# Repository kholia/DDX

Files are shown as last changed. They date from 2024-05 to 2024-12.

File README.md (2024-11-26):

# Intro

For help, please see the [DDX manual](./Manual-for-DDX.md). To purchase an assembled and fully tested DDX-Commercial board please [reach out to us over email](mailto:dhiru.kholia@gmail.com?subject=[DDX]%20Purchasing%20DDX).

The 'Direct Digital Transceiver' (DDX) project. DDX is a radio transceiver
(rig) which is rugged, simple and reliable.

DDX-1 is a 'silent' radio which can be heard almost all over the world!

Current versions:

- DDX-Commercial-7: 5W+ digital transceiver (Commercial, Latest Upgraded Version)

- DDX-1 R1.10: 5W digital transceiver (FOSS)

For a truly portable backpack setup you can combine DDX with the [FT8
Radio](https://play.google.com/store/apps/details?id=com.bunzee.ft8radio)
Android app.

Demo Pic 0

Sample QSO (from Pune to Medellin on 10m, 15691km) on DDX-1:

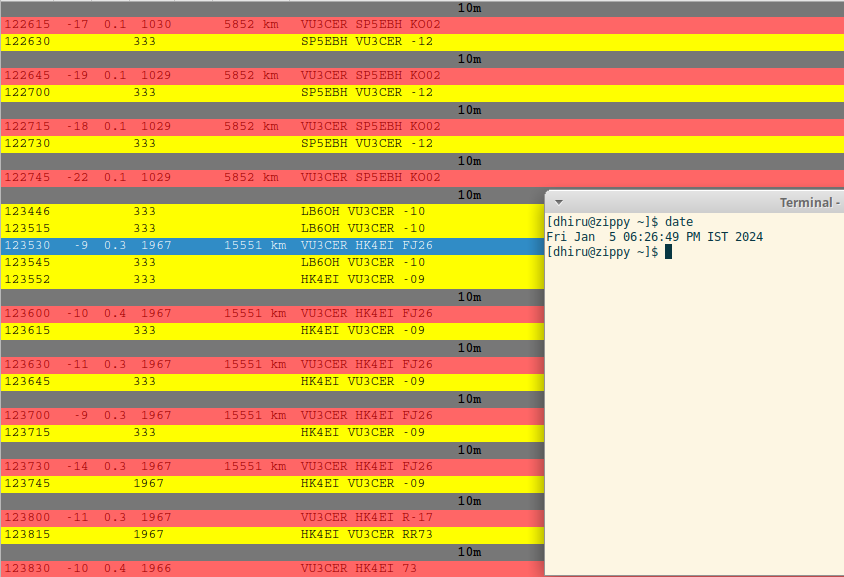
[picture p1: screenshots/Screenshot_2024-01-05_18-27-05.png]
Medellin QSO


QSO with Paraguay:

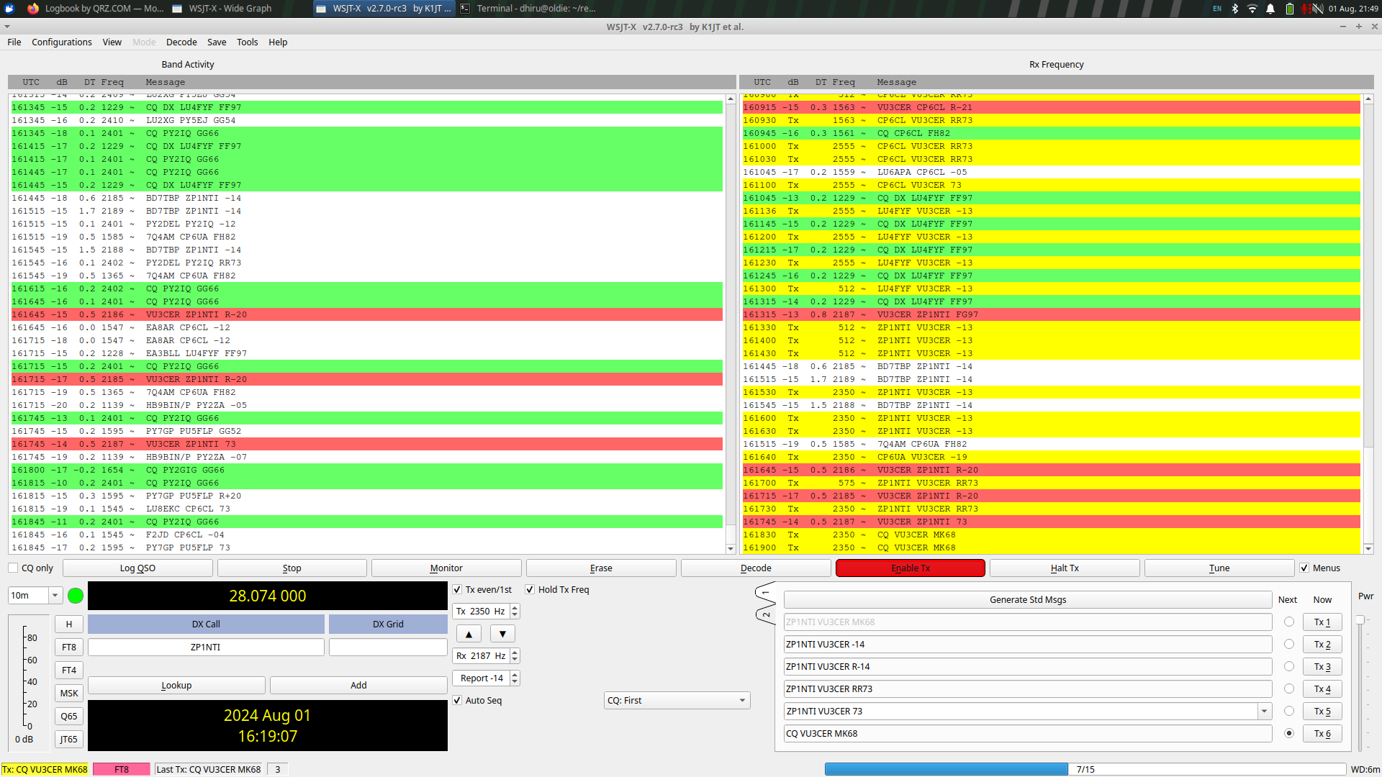
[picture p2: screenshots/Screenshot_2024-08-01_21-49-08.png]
Paraguay QSO


Who doesn't want a QSO from Medellin after binge-watching Narcos? ;)

Another sample QSO with `WW1WW` (Pune to USA):

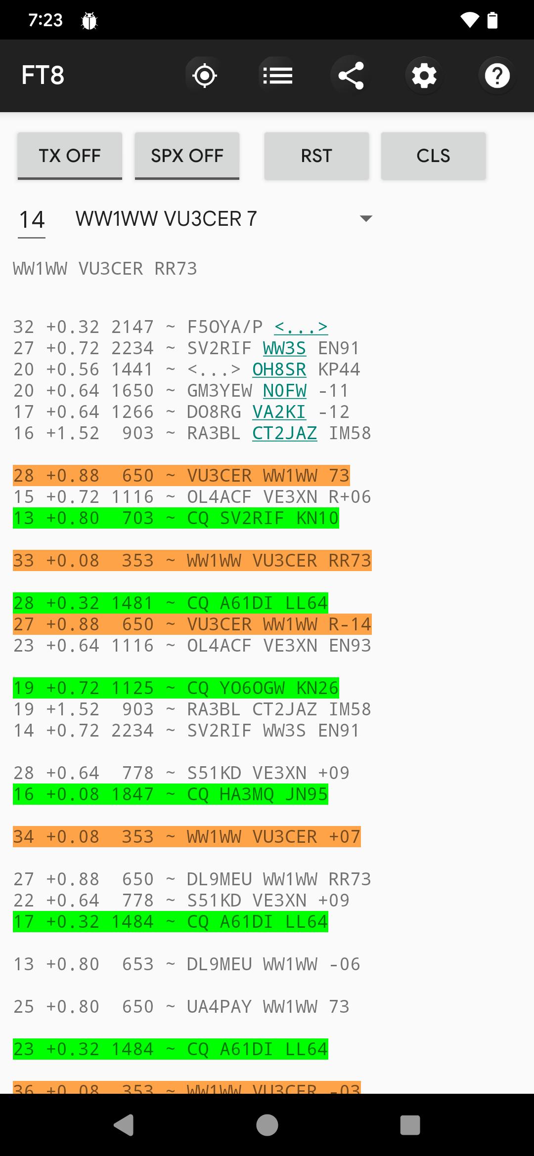
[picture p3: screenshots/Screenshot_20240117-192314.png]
USA QSO


## Render (DDX Commercial)

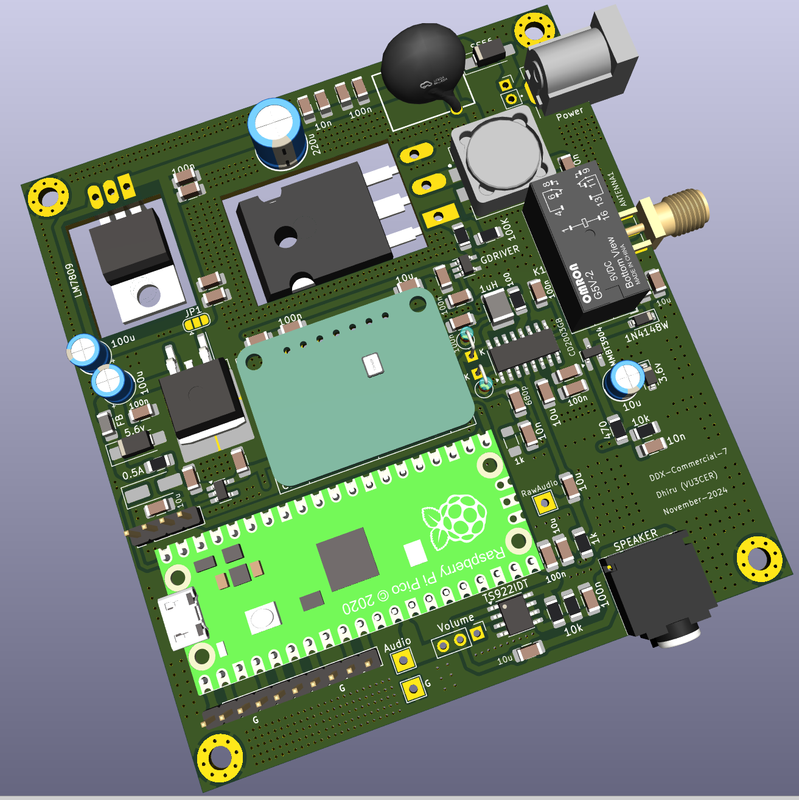
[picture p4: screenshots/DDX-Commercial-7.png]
DDX-Commercial-1


5W+ transceiver based on Pico 2 MCU platform. Beats IC-705 in terms of
efficiency and power consumption!

## Features (DDX-1)

- Single USB-C cable for handling both Audio + CAT control

- True 5W output on all HF bands. It even outputs ~1-2 W @ 50 MHz! (We now just
  need a 6m capable receiver section to build a 6m digital transceiver).

- Rock-solid PA which handles open, short, and bad SWR conditions (1:10 SWR
  tested). We knowingly stress-test it with untuned antennas and still manage
  DX (not a recommended practice for sure though).

- Rock-steady VFO which does NOT drift even under exposed conditions.  Yes - it
  receives WSPR at 28 MHz just fine.

- Reliable T/R switching based on a DPDT relay

- Switchable BPF support to get rid of BCI and other interferences (tested
  against OTH radar + 100 kW AM station in close visual proximity)

- No toroids to wind (assuming an external LPF bank is in use) ;-)

- The IRF510 final remains as cool as a cucumber (Class-D operation) - a small
  heat sink is more than enough.

- Avoids problems associated with the 'audio frequency counting' approach used
  by earlier designs. DDX-1 has a bit-perfect, deterministic TX output.

- It works beautifully with the 'FT8 Radio' app
  (https://github.com/kholia/DigitalRadioReceiverSupport/). The 'FT8 Radio' app
  handles FT8 decoding well in real time (Native MCU decoders offer significantly
  reduced performance at the moment). The app can decode 35++ stations at a time,
  and even large screens can fill up very rapidly - such is the receiver's
  performance (with a BPF)!

- DDX-1 comes with a free, open-source AGPLv3 licensed firmware.

- No calibration is (ever) required. Just pick up DDX-1 and it is ready to go
  on air.

- Low cost (cost-effective)

- Stress tested by WSJT-Z for multiple days

- DDX-1 routinely receives FT8 traffic from 80 to 100+ countries using a simple
  5m long EFHW antenna.

## RX Performance

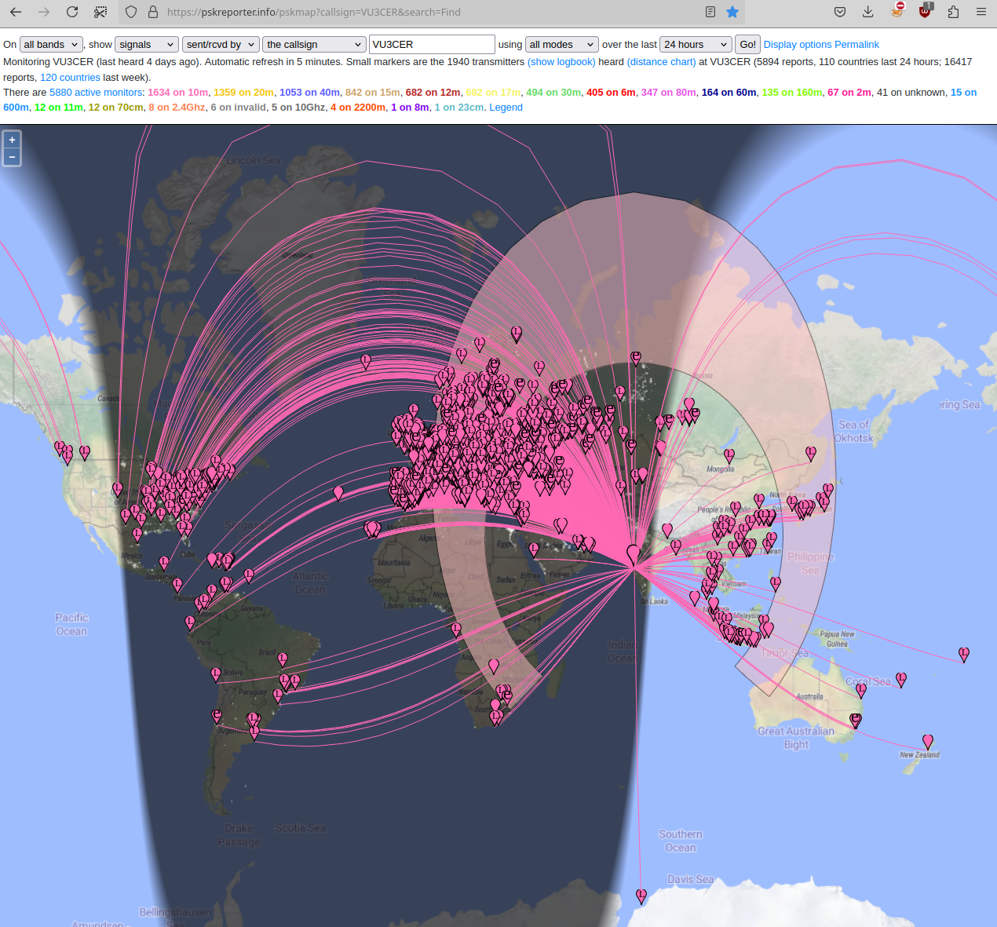
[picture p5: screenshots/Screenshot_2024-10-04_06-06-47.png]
RX Performance


Performance of CD2003-with-BPF is >= 80% of that of RSP1 SDR, at least!

I live right next to a 100 kW AM station (`Pune AIR @ 792 kHz`). Also, there is
an OTH radar nearby operating close to 28 MHz!

## TX Performance

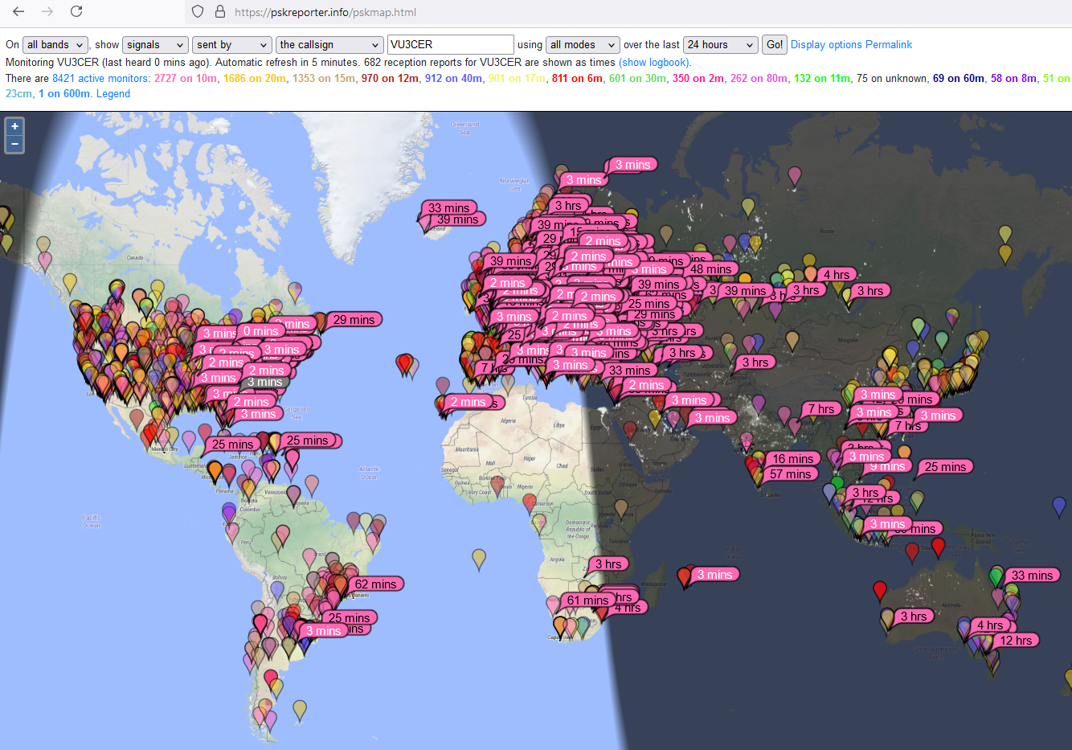
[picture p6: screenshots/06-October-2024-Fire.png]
TX Performance


## VFO stability

It receives WSPR @ 28 MHz ;)

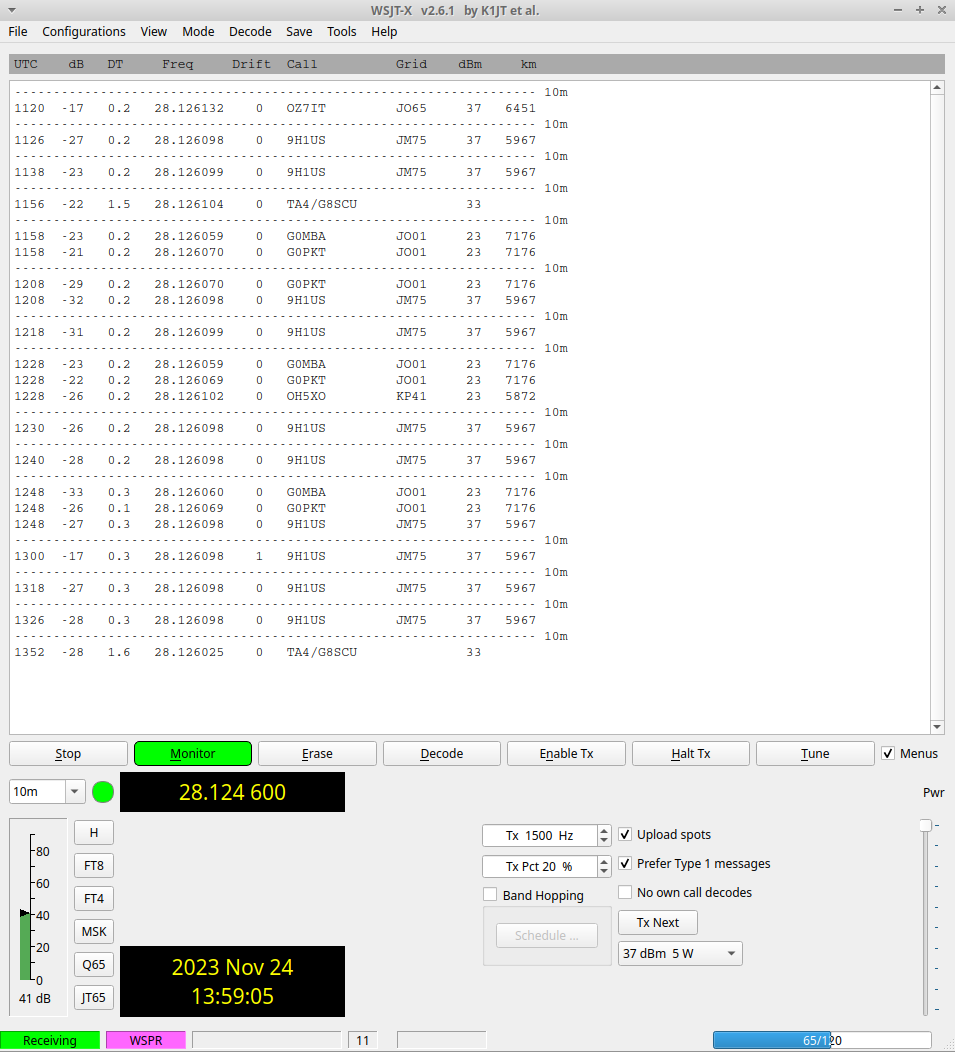
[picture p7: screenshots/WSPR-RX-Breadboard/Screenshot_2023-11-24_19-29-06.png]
Stability


## WSPR TX Performance

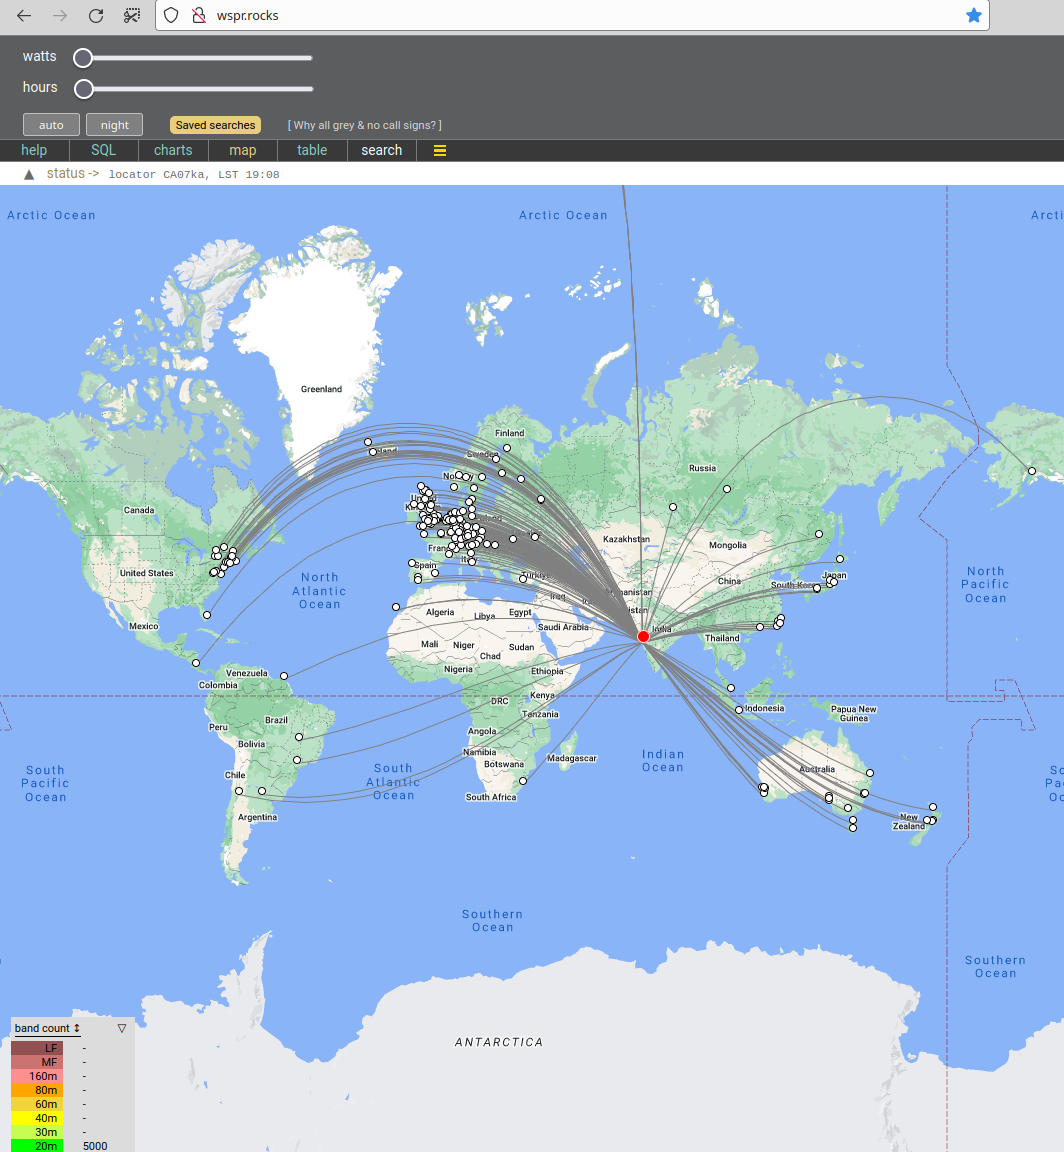
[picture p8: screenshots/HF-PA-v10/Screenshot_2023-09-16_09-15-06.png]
WSPR TX Performance


## QSOs

DDX-1 has already made hundreds of QSOs on air.

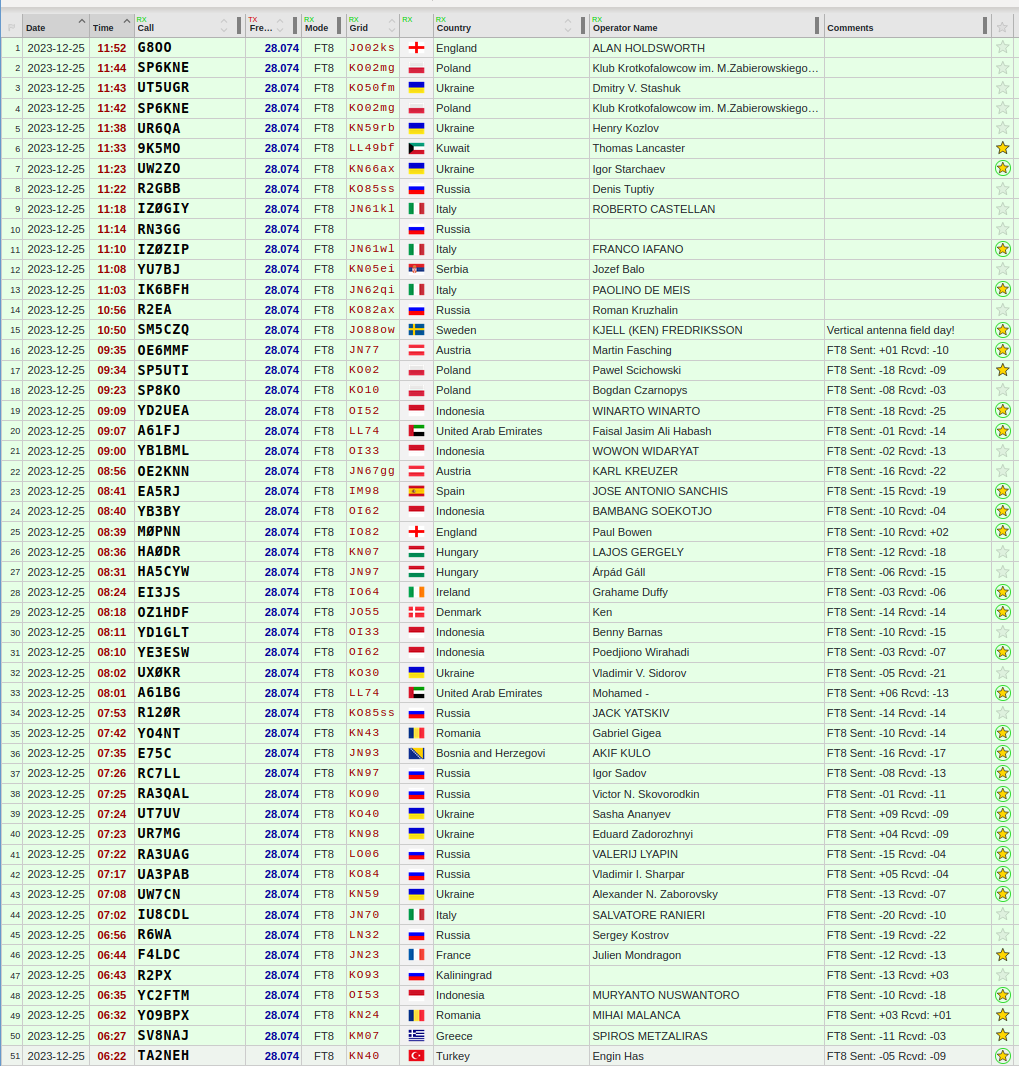
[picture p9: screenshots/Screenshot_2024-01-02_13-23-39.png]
QSOs!


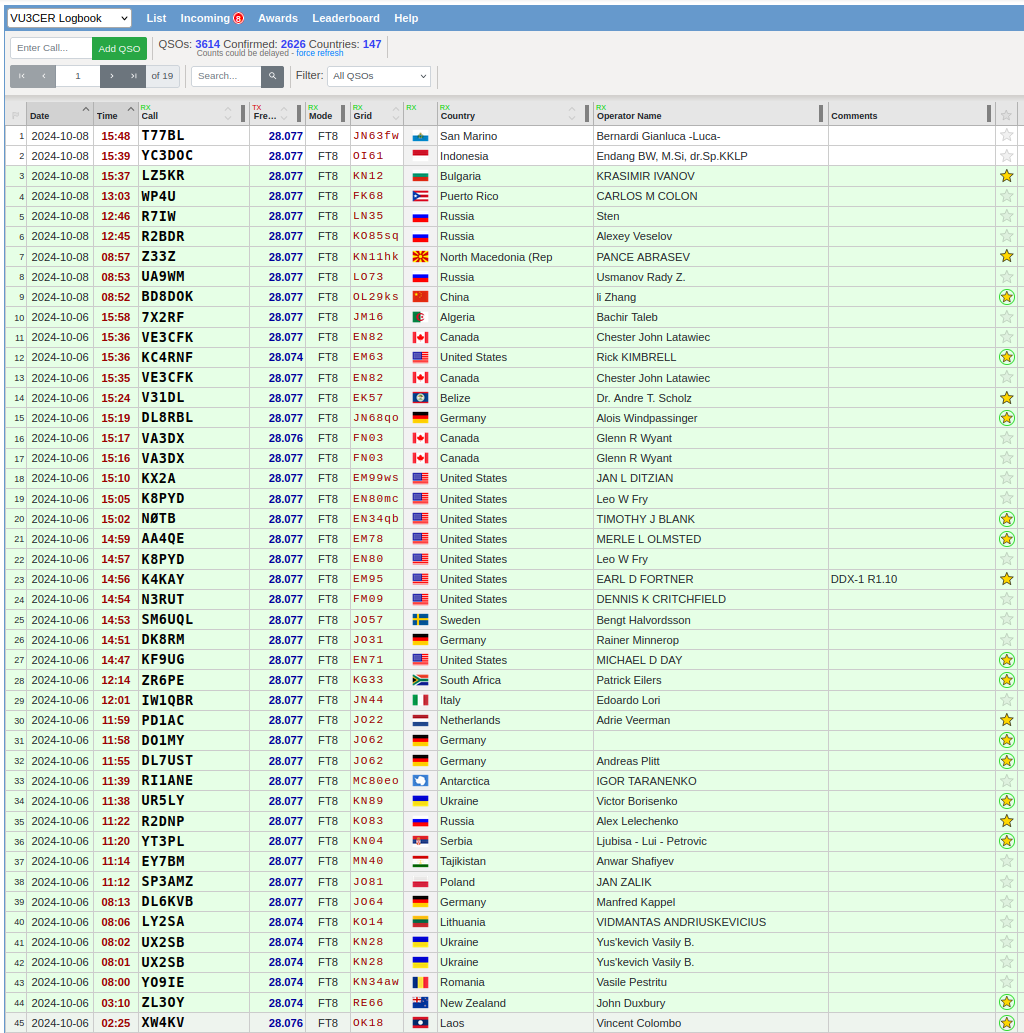
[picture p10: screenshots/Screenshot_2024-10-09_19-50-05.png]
QSOs 2!


## Power sources

DDX-1 was tested with the following power sources.

- SUGON 3005D Adjustable Digital DC Power - RECOMMENDED

- USB battery bank with PD 3.0 and >= 35W output and 15V or 20V PD decoy module
  (RECOMMENDED, safe, portable, durable)

- RUIDENG DPS5020 power supply module (@13v) powered by MEAN WELL / Mornsun SMPS

- 3S "12V" Li-ion 18650 battery pack (can be "volatile")

## Safety Tips

- Use a Common-Mode-Choke (attached between the rig, and the antenna) for
  safety against `return/back RF`.

## Resources

- https://rf-tools.com/lc-filter/

- https://github.com/WB2CBA/ADX (the design that started it all)

- http://www.learningaboutelectronics.com/Articles/Low-pass-filter-calculator.php

- https://github.com/kholia/ConsensusBasedTimeSync (receiver comes from here)

- https://github.com/kholia/Si5351-Module-Clone-TCXO/ (VFO comes from here)

- https://github.com/kholia/HF-PA-v10 (PA comes from here)

  Ruggedness philosophy: https://www.youtube.com/watch?v=4r7wHMg5Yjg

- https://www.kk5jy.net/three-wire-gp/ (recommended antenna - superb for DX)

- https://github.com/kholia/HF-Balcony-Antenna-System (another portable antenna setup)

- https://github.com/batica81/microphone-library-for-pico (Vojislav's work makes DDX-1 possible)

## Joining In

Are you interested in such projects, and spam-free technical discussions?

If yes, you might be interested in joining [the 'HAMBREWERS' Telegram group](https://t.me/+TwzGyKGe8_QI_B3y).

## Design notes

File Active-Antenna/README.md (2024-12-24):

Use KiCad 9.x to use these files.

The default layout is for `PZT2222A`.

Use `Elsie` software for opening the `.lct` files.

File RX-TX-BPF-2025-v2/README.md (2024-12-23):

Use https://tonnesoftware.com/elsie.html to open the .LCT files. The free version of Elise is sufficient.

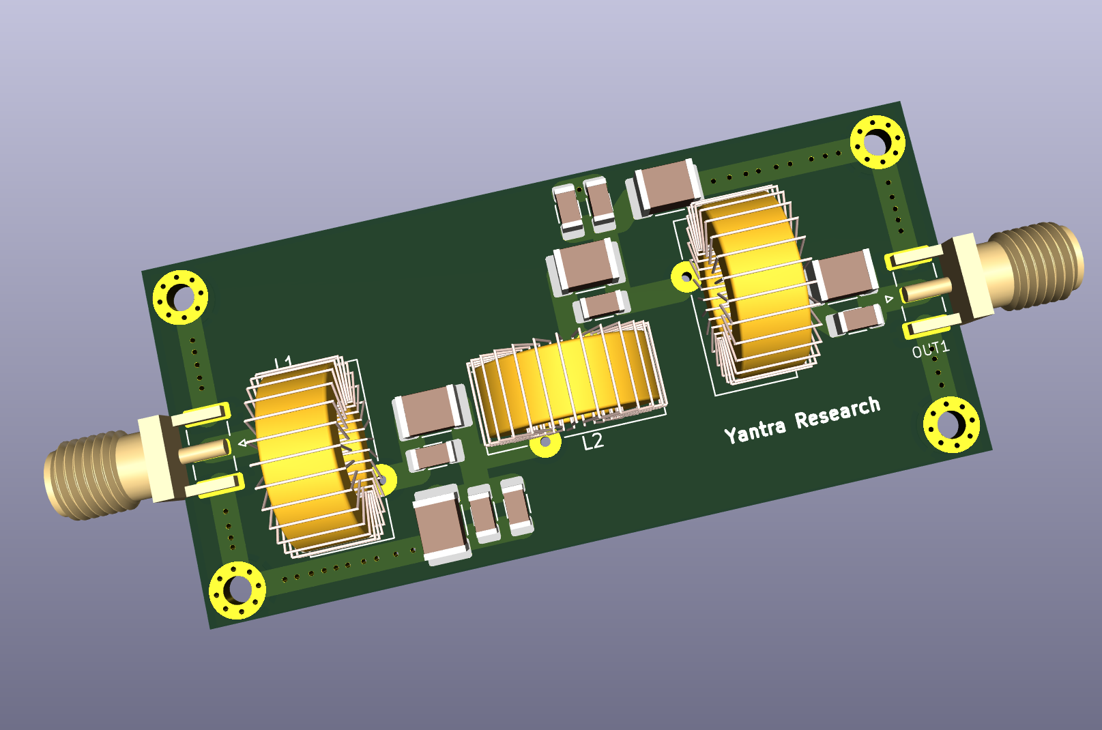
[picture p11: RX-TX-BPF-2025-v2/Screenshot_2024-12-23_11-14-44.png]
3D render


From failure to success reasons:

- Amazing guidance and confidence booster from VU2SPF at LARC 2024 conference

- Being able to measure things properly using my new DE-5000 LCR meter

- Choosing the right program (Elsie) and playing around with it

- Creating a feasible design

  Our previous design used a 27nH inductor - enough said ;)

- Seeing how inductance and capacitor values affect the response shape

- Elsie works much better (produces realistic filters) than Qucs Studio and
  https://markimicrowave.com/technical-resources/tools/lc-filter-design-tool/
  tools.

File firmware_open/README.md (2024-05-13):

Build Process:

```
$ pwd
pico-sdk

$ git checkout develop; git checkout -f
```

[Optional] Apply the following patch:

```
$ git diff
diff --git a/src/boards/include/boards/waveshare_rp2040_zero.h b/src/boards/include/boards/waveshare_rp2040_zero.h
index 281b4dc..858f930 100644
--- a/src/boards/include/boards/waveshare_rp2040_zero.h
+++ b/src/boards/include/boards/waveshare_rp2040_zero.h
@@ -16,6 +16,10 @@
 // For board detection
 #define WAVESHARE_RP2040_ZERO

+#ifndef PICO_XOSC_STARTUP_DELAY_MULTIPLIER
+#define PICO_XOSC_STARTUP_DELAY_MULTIPLIER 64
+#endif
+
 // --- UART ---
 #ifndef PICO_DEFAULT_UART
 #define PICO_DEFAULT_UART 0
```

```
export PICO_SDK_PATH=$HOME/repos/pico-sdk

export PICO_BOARD=waveshare_rp2040_zero  # note

cmake .

cmake -DCMAKE_BUILD_TYPE=Debug .  # for debugging

make -j8
```

```
$ pacmd list-sources
...
  * index: 4
	name: <alsa_input.usb-PaniRCorp_MicNode_123456-00.mono-fallback>
	driver: <module-alsa-card.c>
	flags: HARDWARE HW_MUTE_CTRL HW_VOLUME_CTRL DECIBEL_VOLUME LATENCY DYNAMIC_LATENCY
	state: RUNNING
	suspend cause: (none)
	priority: 9040
	volume: mono: 65536 / 100% / 0.00 dB
	        balance 0.00
	base volume: 64662 /  99% / -0.35 dB
	volume steps: 65537
	muted: no
	current latency: 2.54 ms
	max rewind: 0 KiB
	sample spec: s16le 1ch 16000Hz
	channel map: mono
	             Mono
	used by: 1
	linked by: 1
	configured latency: 24.99 ms; range is 0.50 .. 2000.00 ms
	card: 7 <alsa_card.usb-PaniRCorp_MicNode_123456-00>
	module: 31
	properties:
		alsa.resolution_bits = "16"
		device.api = "alsa"
		device.class = "sound"
		alsa.class = "generic"
		alsa.subclass = "generic-mix"
		alsa.name = "USB Audio"
		alsa.id = "USB Audio"
		alsa.subdevice = "0"
		alsa.subdevice_name = "subdevice #0"
		alsa.device = "0"
		alsa.card = "4"
		alsa.card_name = "MicNode"
		alsa.long_card_name = "PaniRCorp MicNode at usb-0000:04:00.4-1.3.2, full speed"
		alsa.driver_name = "snd_usb_audio"
		device.bus_path = "pci-0000:04:00.4-usb-0:1.3.2:1.0"
		sysfs.path = "/devices/pci0000:00/0000:00:08.1/0000:04:00.4/usb3/3-1/3-1.3/3-1.3.2/3-1.3.2:1.0/sound/card4"
		udev.id = "usb-PaniRCorp_MicNode_123456-00"
		device.bus = "usb"
		device.vendor.id = "cafe"
		device.vendor.name = "PaniRCorp"
		device.product.id = "4011"
		device.product.name = "MicNode"
		device.serial = "PaniRCorp_MicNode_123456"
		device.string = "hw:4"
		device.buffering.buffer_size = "64000"
		device.buffering.fragment_size = "32000"
		device.access_mode = "mmap+timer"
		device.profile.name = "mono-fallback"
		device.profile.description = "Mono"
		device.description = "MicNode Mono"
		module-udev-detect.discovered = "1"
		device.icon_name = "audio-card-usb"
	ports:
		analog-input-mic: Microphone (priority 8700, latency offset 0 usec, available: yes)
			properties:
				device.icon_name = "audio-input-microphone"
	active port: <analog-input-mic>
```

The latency and peformance of the emulated microphone is fine. Check by
recording from this device using Audacity.

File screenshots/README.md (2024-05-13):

DDX-1 prototype is hearing https://www.qrz.com/db/4W8X via the Pico's UAC2 soundcard!

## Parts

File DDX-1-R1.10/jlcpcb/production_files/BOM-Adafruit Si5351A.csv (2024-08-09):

Comment | Designator | Footprint | LCSC
SI5351A | U1 | MSOP-10_3x3mm_P0.5mm | C1509083
1k | R3,R4 | R_0805_2012Metric_Pad1.20x1.40mm_HandSolder | C17513
OSCILLATOR | Y1 | OSC-SMD_4P-L3.2-W2.5-BL_1XTV | C213404
100nF | C1,C2 | C_0805_2012Metric_Pad1.18x1.45mm_HandSolder | C49678

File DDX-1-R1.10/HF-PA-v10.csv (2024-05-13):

Reference | Value | Footprint | Datasheet | Source | Voltage | Qty
BPF1 | Pluggable BPF | footprints:Pluggable-BPF |  | JLCPCB(A) |  | 1
C1, C6, C7, C9, C14, C18, C25-C30, C32, C37, C39, C41 | 100n | Capacitor_SMD:C_1206_3216Metric_Pad1.33x1.80mm_HandSolder | ~ | LCSC | -- mixed values -- | 16
C2, C8, C13, C24, C38, C42, C43, C45, C46 | 10u | Capacitor_SMD:C_1206_3216Metric_Pad1.33x1.80mm_HandSolder | ~ | LCSC |  | 9
C3 | 100p | Capacitor_SMD:C_1206_3216Metric_Pad1.33x1.80mm_HandSolder | ~ | LCSC |  | 1
C4, C19, C35 | 10n | Capacitor_SMD:C_1206_3216Metric_Pad1.33x1.80mm_HandSolder | ~ | LCSC |  | 3
C5, C15, C44 | 100u | Capacitor_THT:CP_Radial_D5.0mm_P2.50mm | ~ | LCSC |  | 3
C10, C12 | 120p | Capacitor_SMD:C_1206_3216Metric_Pad1.33x1.80mm_HandSolder | ~ | LCSC |  | 2
C11 | 200p | Capacitor_SMD:C_1206_3216Metric_Pad1.33x1.80mm_HandSolder | ~ | LCSC |  | 1
C16 | 10u | Capacitor_SMD:C_0805_2012Metric_Pad1.18x1.45mm_HandSolder | ~ | LCSC |  | 1
C17, C20 | 1n | Capacitor_SMD:C_1206_3216Metric_Pad1.33x1.80mm_HandSolder | ~ | LCSC |  | 2
C21, C23, C47 | 100n | Capacitor_SMD:C_0805_2012Metric_Pad1.18x1.45mm_HandSolder | ~ | LCSC |  | 3
C31 | 680p | Capacitor_SMD:C_1206_3216Metric_Pad1.33x1.80mm_HandSolder | ~ | LCSC |  | 1
C36 | 10u | Capacitor_SMD:C_1206_3216Metric_Pad1.33x1.80mm_HandSolder | ~ | LCSC |  | 1
C40 | ~1n | Capacitor_SMD:C_1206_3216Metric_Pad1.33x1.80mm_HandSolder | ~ | LCSC |  | 1
CW_KEY1 | Conn_01x02 | Connector_PinHeader_2.54mm:PinHeader_1x02_P2.54mm_Vertical | ~ | NA |  | 1
D1, D2 | SS34 | Diode_SMD:D_SMA_Handsoldering | https://www.tme.eu/Document/4534c3d1273464918563ce78bdeb2ece/SS34-E3-57T.pdf | LCSC |  | 2
D3, D8, D9 | 1N4148 | Diode_THT:D_DO-35_SOD27_P2.54mm_Vertical_KathodeUp | https://www.vishay.com/docs/81857/1n4148.pdf | LCSC |  | 3
D4 | 5.1V | Diode_SMD:D_MiniMELF | ~ | LCSC |  | 1
D5 | 5.6v 5W | Diode_THT:D_DO-15_P3.81mm_Vertical_KathodeUp | ~ | LCSC |  | 1
EXT_ATU1 | EXT_ATU | footprints:PJ-307_Modded | https://cdn.hackaday.io/files/1813827760247488/JW-PJ-307-5_35mm-stereo-pcb-socket.pdf |  |  | 1
F1 | 2A | Fuse:Fuse_1812_4532Metric_Pad1.30x3.40mm_HandSolder | ~ | LCSC |  | 1
H1-H4 | MountingHole_Pad | MountingHole:MountingHole_3.2mm_M3_Pad_Via | ~ | NA |  | 4
J1 | Conn_01x06 | Connector_PinHeader_2.54mm:PinHeader_1x10_P2.54mm_Vertical | ~ | NA |  | 1
JP1, JP4 | Jumper_2_Open | Jumper:SolderJumper-2_P1.3mm_Open_TrianglePad1.0x1.5mm | ~ | NA |  | 2
JP2 | Power_Switch | Jumper:SolderJumper-3_P1.3mm_Open_RoundedPad1.0x1.5mm_NumberLabels | ~ | NA |  | 1
JP3 | Jumper_2_Open | Connector_PinHeader_2.54mm:PinHeader_1x02_P2.54mm_Vertical | ~ | NA |  | 1
K1 | Omron G5V-2 / OEN 46-05-2C | Relay_THT:Relay_DPDT_Omron_G5V-2 | http://omronfs.omron.com/en_US/ecb/products/pdf/en-g5v_2.pdf | LCSC |  | 1
L1, L2 | 360n | Inductor_THT:L_Toroid_Vertical_L10.0mm_W5.0mm_P5.08mm | ~ | DIY on Toroid |  | 2
L4 | Ferrite Bead (2A) | Inductor_SMD:L_0805_2012Metric_Pad1.05x1.20mm_HandSolder | 330Ohm 2.5A 25% 0805 Multilayer Chip Ferrite Bead - UPZ2012E331-2R5TF - Shenzhen Sunlord - LCSC | LCSC |  | 1
L5 | 1uH | Inductor_SMD:L_1206_3216Metric_Pad1.22x1.90mm_HandSolder | ~ | LCSC |  | 1
Power1 | DC-005 (Barrel Jack) | footprints:XKB_DC-005-5A-2.0_Modded | https://www.lcsc.com/product-detail/Power-Connectors_XKB-Enterprise-DC-005-5A-2-0_C381116.html | LCSC |  | 1
Q1, Q4, Q5 | 2N3904 | Package_TO_SOT_THT:TO-92_HandSolder | https://www.onsemi.com/pdf/datasheet/2n3903-d.pdf | LCSC |  | 3
Q2 | IRF510 | Package_TO_SOT_THT:TO-220-3_Horizontal_TabDown | https://www.lcsc.com/product-detail/MOSFETs_Vishay-Intertech-IRFI510GPBF_C506484.html | Mouser / LCSC (IRFI510G) |  | 1
Q3 | AOD407 | Package_TO_SOT_SMD:TO-252-2 | http://aosmd.com/pdfs/datasheet/AOD407.pdf | LCSC |  | 1
R1 | 100K | Resistor_SMD:R_1206_3216Metric_Pad1.30x1.75mm_HandSolder | ~ | LCSC |  | 1
R2, R10, R11 | 10k | Resistor_SMD:R_1206_3216Metric_Pad1.30x1.75mm_HandSolder | ~ | LCSC |  | 3
R4 | 470 | Resistor_SMD:R_1206_3216Metric_Pad1.30x1.75mm_HandSolder | ~ | LCSC |  | 1
R6 | 100 | Resistor_SMD:R_1206_3216Metric_Pad1.30x1.75mm_HandSolder | ~ | LCSC |  | 1
R7 | 1k | Resistor_SMD:R_1206_3216Metric_Pad1.30x1.75mm_HandSolder | ~ | LCSC |  | 1
R8, R9 | 4.7k | Resistor_SMD:R_1206_3216Metric_Pad1.30x1.75mm_HandSolder | ~ | LCSC |  | 2
R12 | 3.3R | Resistor_SMD:R_0805_2012Metric_Pad1.20x1.40mm_HandSolder | ~ | LCSC or short (preferred)! |  | 1
Rb1 | 1k | Resistor_SMD:R_1206_3216Metric_Pad1.30x1.75mm_HandSolder | ~ | LCSC |  | 1
Rf1 | 4.7k | Resistor_SMD:R_1206_3216Metric_Pad1.30x1.75mm_HandSolder | ~ | LCSC |  | 1
RF_OUT1 | SMA | Connector_Coaxial:SMA_Samtec_SMA-J-P-X-ST-EM1_EdgeMount | ~ | LCSC / https://www.ktron.in/ |  | 1
Rin1 | 1k | Resistor_SMD:R_1206_3216Metric_Pad1.30x1.75mm_HandSolder | ~ | LCSC |  | 1
Rl1 | 470 | Resistor_SMD:R_1206_3216Metric_Pad1.30x1.75mm_HandSolder | ~ | LCSC |  | 1
RV1 | 10k | Connector_PinHeader_2.54mm:PinHeader_1x03_P2.54mm_Vertical | ~ | NA |  | 1
RV2 | 20k | Connector_PinHeader_2.54mm:PinHeader_1x03_P2.54mm_Vertical | ~ | NA |  | 1
RZ1 | RP2040-Zero | footprints:RP2040-Zero | https://www.waveshare.com/wiki/RP2040-Zero |  |  | 1
SPK1 | SPEAKER | footprints:PJ-307_Modded | https://cdn.hackaday.io/files/1813827760247488/JW-PJ-307-5_35mm-stereo-pcb-socket.pdf |  |  | 1
T1 | Bifilar XFMR | footprints:IND_SRF1260A-4R7Y-Longer-Pads | https://www.digikey.com/en/products/detail/bourns-inc/SRF1260A-4R7Y/4340156 | Mouser / DigiKey / Farnell |  | 1
U1 | L7805 (D2PAK) | Package_TO_SOT_SMD:TO-263-2 | https://www.st.com/resource/en/datasheet/l78.pdf | LCSC |  | 1
U2 | UCC27517ADBVR | Package_TO_SOT_SMD:SOT-23-5_HandSoldering | https://www.lcsc.com/product-detail/Gate-Drive-ICs_Texas-Instruments-UCC27517ADBVR_C2653784.html | LCSC |  | 1
U3 | L7812 | Package_TO_SOT_SMD:TO-252-2 | https://www.st.com/resource/en/datasheet/l78.pdf | LCSC |  | 1
U4 | AMS1117-3.3 | Package_TO_SOT_SMD:SOT-223-3_TabPin2 | http://www.advanced-monolithic.com/pdf/ds1117.pdf | LCSC (Hottech make is fine!) |  | 1
U5 | SI5351_Module | footprints:SI5351 Module | https://github.com/kholia/Si5351-Module-Clone-TCXO/ (MUST!) | TCXO is a must! |  | 1
U7 | CD2003GB_GP | Package_DIP:DIP-16_W7.62mm | https://www.ak-modul-bus.de/cat/documentation/CD2003.pdf | eBay / https://inkocean.in/ |  | 1
U8 | MCP6002 | Package_DIP:DIP-8_W7.62mm | https://www.microchip.com/en-us/product/mcp6002 | Mouser / DigiKey / Semikart |  | 1

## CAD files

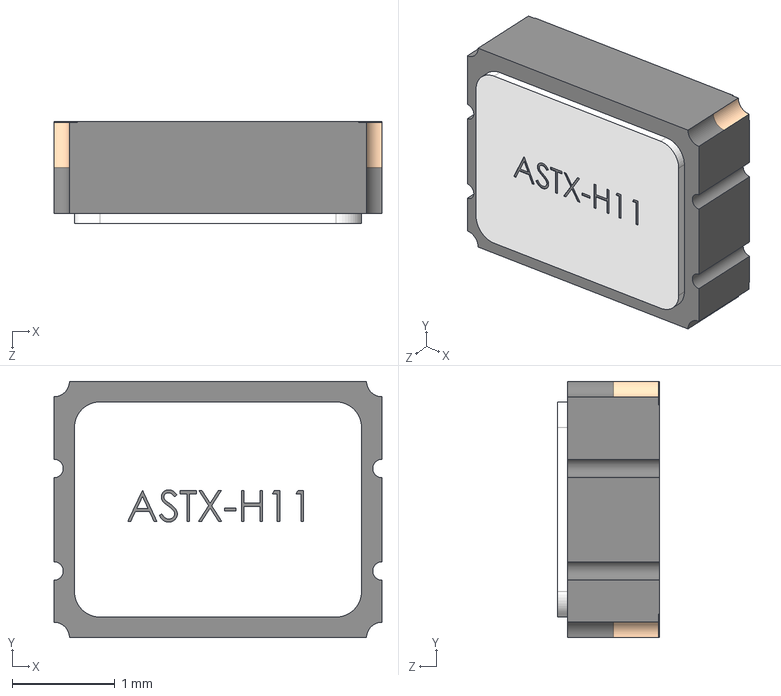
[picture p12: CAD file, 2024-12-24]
Active-Antenna/models/ASTX-H11-25.000MHZ-T.step
3.20 x 2.50 x 1.00 mm

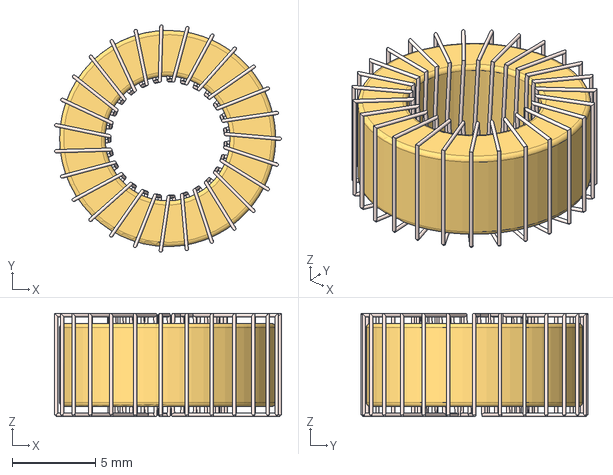
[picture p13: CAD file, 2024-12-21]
RX-TX-BPF-2025-v2/models/T50-6.step
13.7 x 13.7 x 6.20 mm

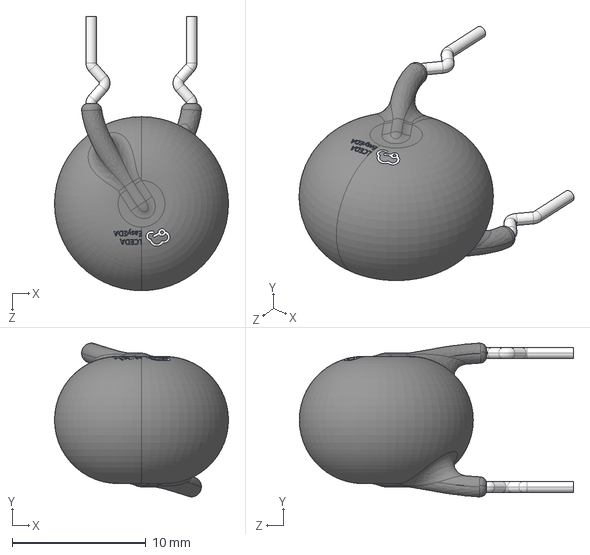
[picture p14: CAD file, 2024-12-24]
Active-Antenna/models/RES-TH_L13.0-W10.0-H21.0-P7.50-D0.8-S10.00.step
13.0 x 11.5 x 20.5 mm

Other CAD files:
experiments/DDX-EVO-3/models/TO220andHeatsinkAssy.STEP
experiments/DDX-EVO-2/models/TO220andHeatsinkAssy.STEP
DDX-1/models/5019.STEP
DDX-Commercial-1/DDX-QSD-1/models/CUI_DEVICES_SJ1-3523N.step
DDX-Commercial-1/DDX-QSD-2/models/SO-8_S_LIT.step
DDX-Commercial-1/Dongle/models/XIAO RP2350_.step
DDX-Commercial-1/Pico-WSPR-TX-250mW-board/models/SMD_4P-L6.0-W6.0-H5.0-LS10.0-P4.5.step
DDX-EVO-3/models/TO-220-3 Bend Mirror.stp
experiments/Digital-PA-Push-Pull-Final-v2/models/SMA-angled.STEP
experiments/Digital-PA-Push-Pull-Final-v3-Simple/models/SMA-angled.STEP
experiments/MiniSWR-Interface/models/CON-SMA-EDGE-S--3DModel-STEP-56544.STEP
experiments/Pluggable-BPF-Design/BPF-1.step
experiments/RX-TX-BPF-2025/RX-TX-BPF/models/T50-6.step
DDX-Commercial-1/DDX-QSD-1/models/SO-8_S_LIT.step
DDX-Commercial-1/DDX-QSD-2/models/CUI_DEVICES_SJ1-3523N.step
Active-Antenna/models/1564889-62.stp
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

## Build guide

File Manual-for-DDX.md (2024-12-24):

# Overview

DDX is a rugged 5W+ digital transceiver featuring manual band switching and
flexible power capabilities. Designed for reliability and ease of use, it's
perfect for digital modes like FT8.

DDX is brought to you by `Yantra Research`!

# Supported Modes

- FT8

# Other Modes

- WSPR (a dedicated firmware is in the works)

- FT4 (support can be added as per demand)

# Power Specifications

- ~5W output @ 15v on 28 MHz (after strong BPF)

- ~7W output @ 20v on 28 MHz (after strong BPF)

# Requirements

The following items are required for operating DDX:

- Power Source (Choose one)

  - USB PD 3.0 battery bank (portable and flight-safe option) - RECOMMENDED!

  - Traditional "12V" battery (4S LFP or 3S Li-ion or lead-acid)

  20v input (typically via PD 3.0) is RECOMMENDED!

- An antenna

  For field operations, we recommend getting / building an EFHW antenna.

  See https://github.com/kholia/HF-Balcony-Antenna-System for an example.

  https://www.kk5jy.net/three-wire-gp/ is a solid choice as well.

  The `Banggood` store also sells an EFHW 49:1 transformer for a reasonable
  price.

- Laptop / PC / Android phone

  The laptop can run the standard WSJT-X software.

  On Android, use our `FT8 Radio` app from Google Play Store.

- TX-BPF (*HIGHLY RECOMMENDED* for good performance and compliance, *REQUIRED* if you have radio interference problems)

  Update (December-2024): [We have open-sourced our TX-BPF designs here](https://github.com/kholia/DDX/tree/master/RX-TX-BPF-2025-v2).

  Tip: Buy one filter for your favorite band and then keep adding more later on

  Sources: eBay / AliExpress

  Cost: ~45 USD

  This TX-BPF helps your other radios as well and is a one-time investment.

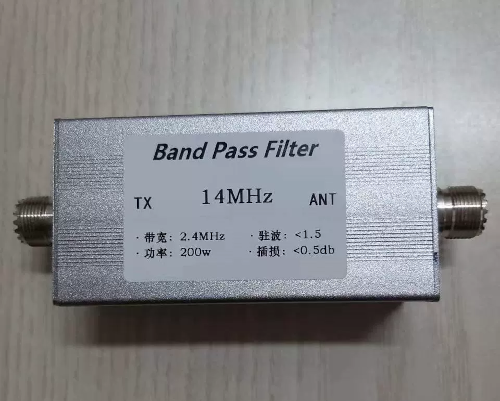
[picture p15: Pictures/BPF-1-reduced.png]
TX-BPF 1
  

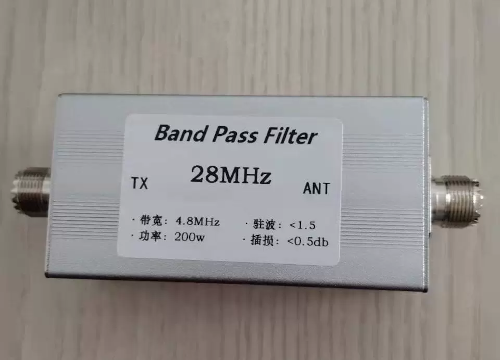
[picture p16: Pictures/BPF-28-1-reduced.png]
TX-BPF 2
  

  While many amateur radio operators focus *solely* on antenna optimization,
  the significant benefits of TX-BPF filters are often overlooked or
  under-discussed in the hobby!

  Even with HOA antenna restrictions, you can still optimize your station's
  performance through proper TX-BPF filtering.

- [Optional] Common-mode choke (CMC)

  Can be useful depending on your operating conditions.

- [Optional] PD Trigger Module

  Something like [this module](https://punoscho.in/product/usb-qc-pd-afc-trigger-decoy-board-module-15v/).

- [Optional] 10 meters plus of coax cable if operating an EFHW antenna.

# Supplied components

- 2 x mica insulator pads (for IRF510 and 7809 regulator)

- 2 x TO-220 bushes (for IRF510 and 7809 regulator)

- 2 x steel screws + spring washers + regular washers + nuts

- 1 x 5.5x2.1mm DC power cable (male connector)

- [Optional] Small TO-220 + TO-3 heat sinks

- [Optional] M3 standoffs

# Assembly Steps

- Connect the fully assembled DDX board to a heat sink (heat sink can supplied
  as an option).

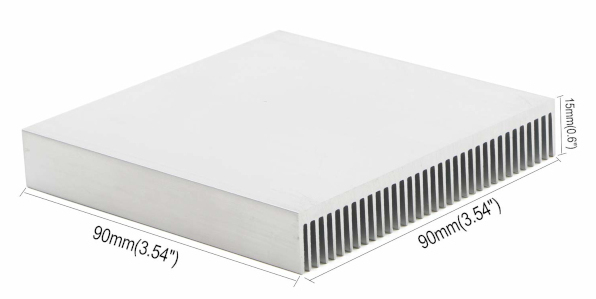
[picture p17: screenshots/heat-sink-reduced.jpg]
Heat Sink
  

  This above heat sink needs two holes to be made in it. A 3mm bit on a battery
  powered hand drill is sufficient for the job.

  [ALTERNATE HEAT SINKING OPTION]

  You can also use two smaller heat sinks like the following:

  - https://etstore.in/index.php/product/8087/ (Small TO-220 heatsink)

  - https://www.electronicscomp.com/heat-sink-to3-40mm (Yes - a TO-3 heatsink)

  The whole assembled PCB can then be raised on M3 standoffs.

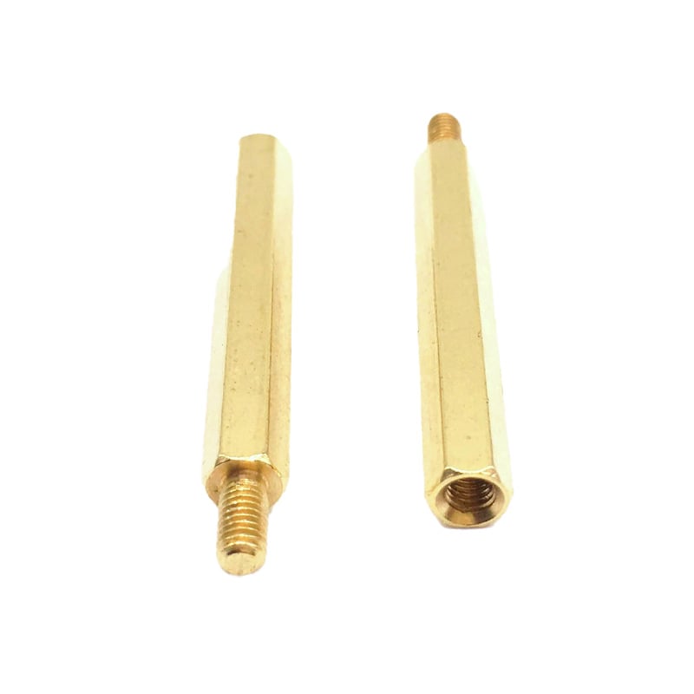
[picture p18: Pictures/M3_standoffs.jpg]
M3 standoffs
  

  https://robu.in/product/m3-x-35mm-male-to-female-brass-hex-threaded-pillar-standoff-spacer-12-pcs/

- Put the DDX board into a suitable enclosure of your choice. This is optional
  for home usage.

- Done!

# Power-on sequence

- First, connect the Micro-USB cable from DDX to the PC or phone

- Next, turn on the DC power supply (using the onboard switch)

# Usage (with WSJT-X)

* Configure WSJT-X with your callsign and grid.

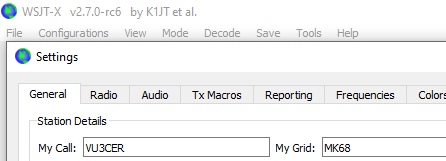
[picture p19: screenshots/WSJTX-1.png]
WSJT-X 1
  

* Select `MicNode` as the Soundcard Input.

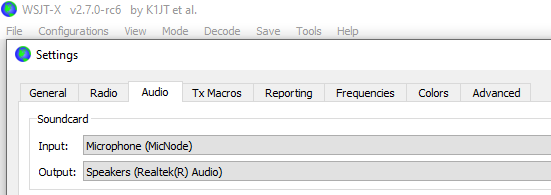
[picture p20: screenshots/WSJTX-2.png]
WSJT-X 2
  

  Tip: The `Soundcard Output` setting does NOT matter.

* Ensure the following default settings are present.

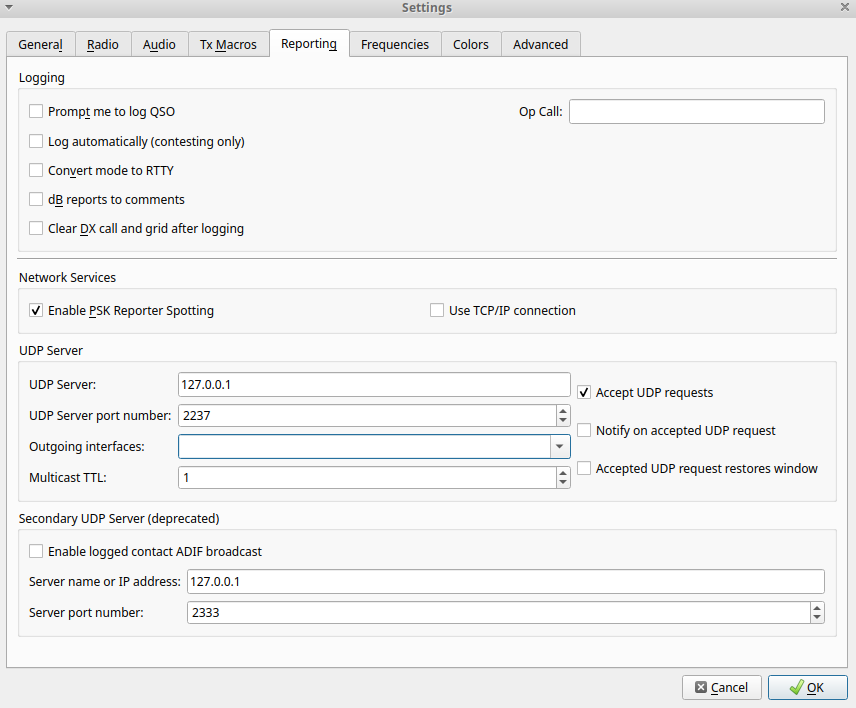
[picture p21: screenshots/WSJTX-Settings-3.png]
WSJT-X 3
  

* Launch the [wsjtx_helper/transceiver_server.exe](https://github.com/kholia/DDX/raw/refs/heads/master/wsjtx_helper/transceiver_server.exe) program.

* That's it!

# Usage (with `FT8 Radio` app on Android)

* Install `FT8 Radio` app from Google Play Store.

* Launch the app and go to settings (`gear icon`).

  Configure settings and choose `DDX` as the radio.

  NB: Restart the app forcefully.

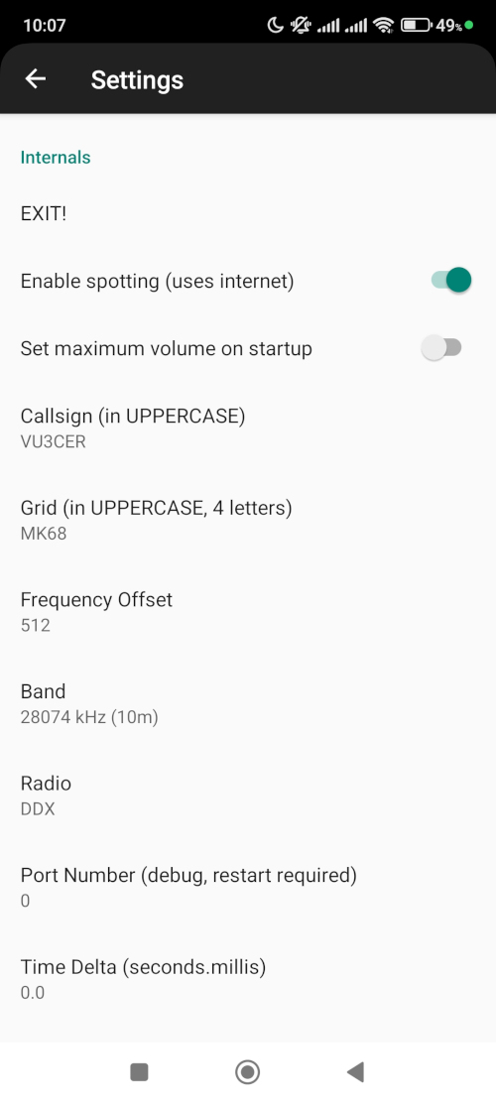
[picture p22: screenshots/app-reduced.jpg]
FT8 Radio
  

* Connect DDX to the phone using a Micro-USB cable and a reliable OTG adapter.

* Done!

PS: See https://github.com/kholia/DigitalRadioReceiverSupport/tree/master/NewApp for more help.

# Tips

For best results, we recommend syncing time on your laptop / PC using
https://www.timesynctool.com/ software.

On Android, open the https://time.is/ site to see the clock delta.

# Features

- It comes as a fully tested-on-air board with minimal assembly required.

- Single USB connection for Audio + CAT control

  DDX has a built-in 'sound card'

- Rock-solid PA which handles open, short, and bad SWR conditions (~10:1 SWR
  tested)

- Rock-steady VFO which does NOT drift even under exposed conditions. Yes - it
  receives WSPR at 28 MHz just fine.

- Reliable T/R switching based on a DPDT relay

- No toroids to wind with the external TX-BPF in use ;-)

- The final MOSFET remains as cool as a cucumber (Class-D operation)

- DDX has a bit-perfect, deterministic TX output

  We simply do NOT use the audio tones emitted by the PC (or phone).

  We implement the various FSK encoders on the MCU itself.

- It works beautifully with the 'FT8 Radio' app
  (https://github.com/kholia/DigitalRadioReceiverSupport/). The 'FT8 Radio' app
  handles FT8 decoding well in real time (Native MCU decoders offer significantly
  reduced performance at the moment). The app can decode 35++ stations at a time,
  and even large screens can fill up very rapidly - such is the receiver's
  performance (with a BPF)!

  Note: The FT8CN app is NOT supported.

- No calibration is usually required. Just pick up DDX and it is ready to go on
  air. It comes with 26 MHz 0.5ppm TCXO as a standard.

- Low cost (cost-effective)

- Stress tested by WSJT-Z and WSJT-X for multiple days

- DDX routinely receives FT8 traffic from 80 to 100+ countries using a simple
  5m long EFHW antenna with a BPF attached.

  And we use a SMPS with RuiDeng DC-DC buck module with >= 100mV ripple in our
  testing work to "stress out" the receiver.

- All this in a compact (< 100mmx100mm) size!

# Limitations

- Special / complex callsigns are NOT supported yet.

- While we have a fully-functional VFO, it is locked to certain FT8 frequencies
  for safety reasons. You can request addition of more frequencies as needed.

# Firmware Upgrade

Note: DDX comes with the firmware installed on it.

- Disconnect all power sources

- Unplug the Pico MCU board from the computer

- Keep the white button on the Pico MCU board pressed, and connect Pico to the
  computer via a USB cable

- Upload the supplied `.uf2` firmware file to the new drive that opens up on
  your computer

- Done!

# Render

DDX-Commercial-1

# Support Resources

- [The Global Communications Transceiver](https://www.youtube.com/watch?v=b82O-rVQVpk) - Video demo of older version

- [FT8 Radio App demo](https://www.youtube.com/watch?v=OX8Knu0yh6M)

- [DDX contest writeup](https://www.electronicwings.com/users/DhiruKholia/projects/4382/global-communications-transceiver)

- https://github.com/kholia/wsjtx

# Pricing

- Option 1: Kit with all components (including Pico 2 and TCXO Si5351 module) and blank PCB: 2499 INR (shipping within India included).

- Option 2: 80% assembled boards with remaining components (including Pico 2 and TCXO Si5351 module): 3999 INR (shipping within India included).

# Note

We do NOT have the resources to provide any support at the moment. We expect
our customers to be hands-on `home brewers`.

DDX is NOT (yet) targeted at `appliance operator` category of amateur radio
operators.

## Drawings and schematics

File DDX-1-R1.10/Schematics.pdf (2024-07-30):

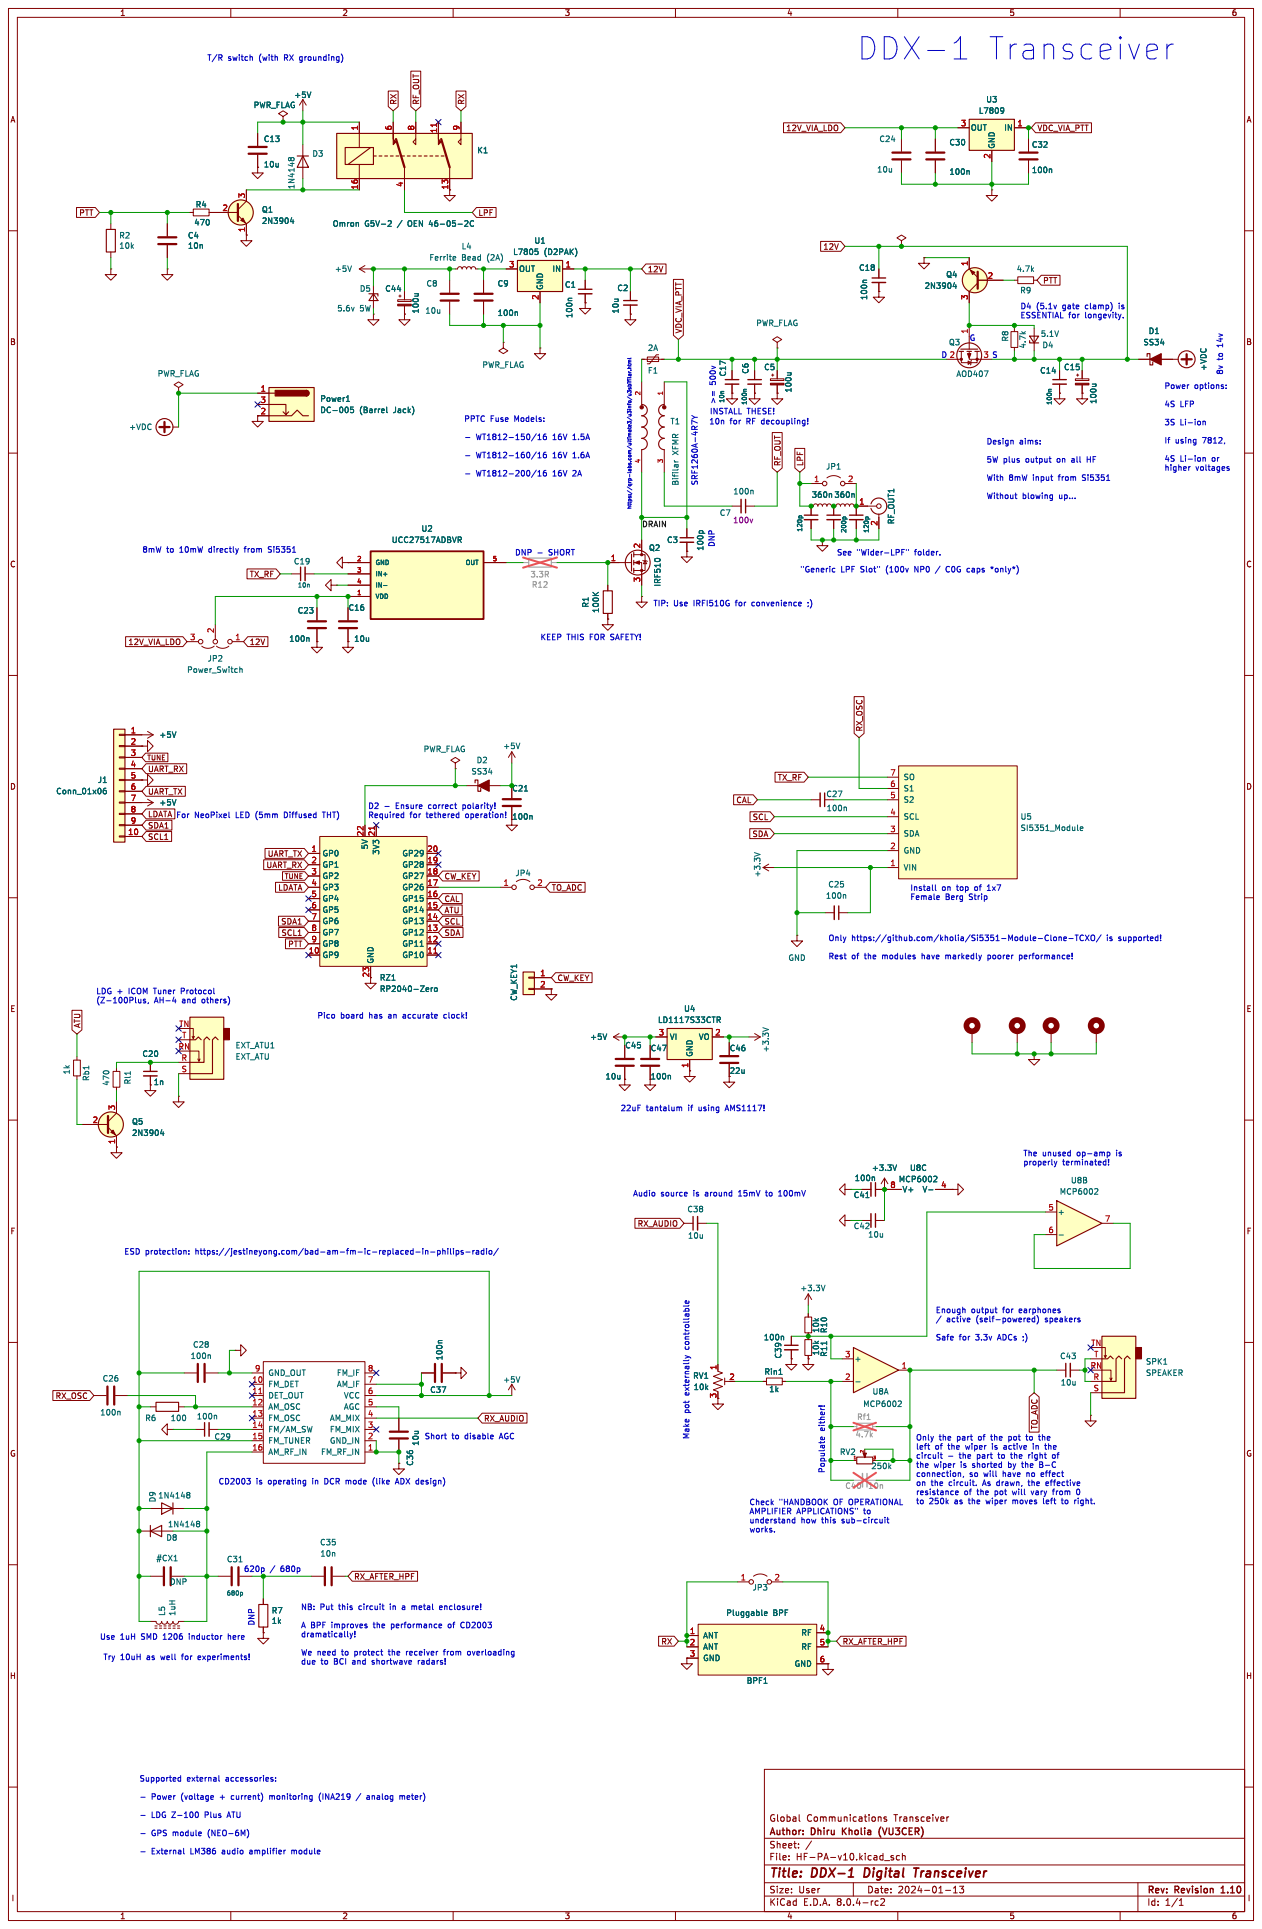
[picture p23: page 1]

T/R switch (with RX grounding)

3 +VDC
D4 (5.1v gate clamp) is ESSENTIAL for longevity. D

to 250k as the wiper moves left to right. DNP

SDesign aims: 5W plus output on all HF With 8mW input from Si5351 Without blowing up...

Enough output for earphones

left of the wiper is active in the
the wiper is shorted by the B-C

Check "HANDBOOK OF OPERATIONAL AMPLIFIER APPLICATIONS" to

dramatically! We need to protect the receiver from overloading

Try 10uH as well for experiments!

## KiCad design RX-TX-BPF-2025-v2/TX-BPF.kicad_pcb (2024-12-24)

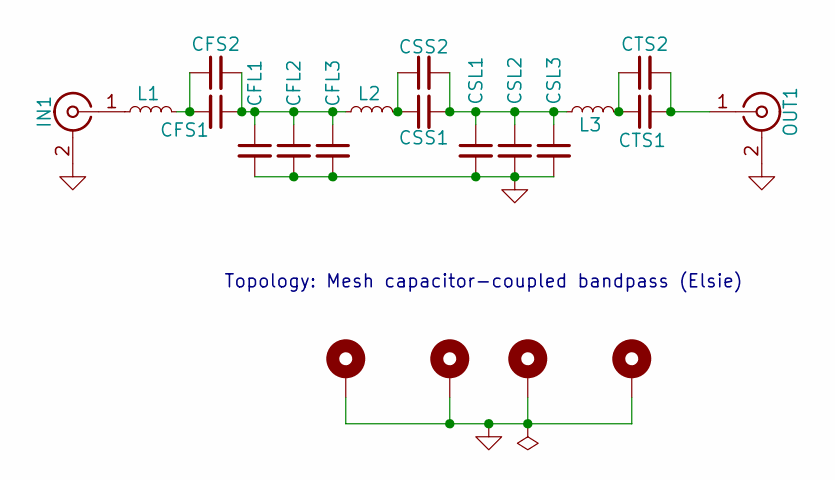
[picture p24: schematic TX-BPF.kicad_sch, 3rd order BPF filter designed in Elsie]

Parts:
CFL1, CFL2: 100n; C_1206_3216Metric_Pad1.33x1.80mm_HandSolder
CFL3: 100n; C_1812_4532Metric_Pad1.57x3.40mm_HandSolder
CFS1: 100n; C_1206_3216Metric_Pad1.33x1.80mm_HandSolder
CFS2: 100n; C_1812_4532Metric_Pad1.57x3.40mm_HandSolder
CSL1, CSL3: 100n; C_1206_3216Metric_Pad1.33x1.80mm_HandSolder
CSL2: 100n; C_1812_4532Metric_Pad1.57x3.40mm_HandSolder
CSS1: 100n; C_1812_4532Metric_Pad1.57x3.40mm_HandSolder
CSS2: 100n; C_1206_3216Metric_Pad1.33x1.80mm_HandSolder
CTS1: 100n; C_1206_3216Metric_Pad1.33x1.80mm_HandSolder
CTS2: 100n; C_1812_4532Metric_Pad1.57x3.40mm_HandSolder
H1, H2, H3, H4: MountingHole_Pad; MountingHole_2.2mm_M2_Pad_Via
IN1: SMA; SMA_Samtec_SMA-J-P-H-ST-EM1_EdgeMount
L1, L2, L3: L_Small; T50-6
OUT1: SMA; SMA_Samtec_SMA-J-P-H-ST-EM1_EdgeMount

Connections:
GND: CFL1.2, CFL2.2, CFL3.2, CSL1.2, CSL2.2, CSL3.2, H1.1, H2.1, H3.1, H4.1, IN1.2 (Ext), OUT1.2 (Ext)
unnamed: CFL1.1, CFL2.1, CFL3.1, CFS1.1, CFS2.2, L2.1
unnamed: CFS1.2, CFS2.1, L1.2
unnamed: CSL1.1, CSL2.1, CSL3.1, CSS1.2, CSS2.2, L3.1
unnamed: CSS1.1, CSS2.1, L2.2
unnamed: CTS1.1, CTS2.1, L3.2
unnamed: IN1.1 (In), L1.1
unnamed: CTS1.2, CTS2.2, OUT1.1 (In)

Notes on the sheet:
Topology: Mesh capacitor-coupled bandpass (Elsie)

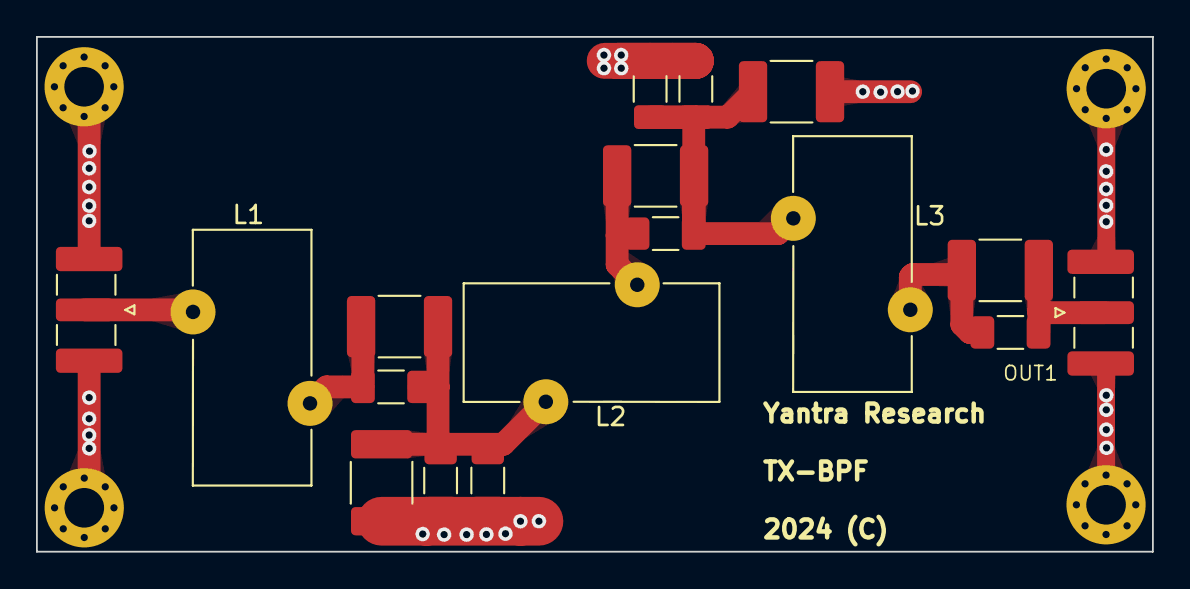
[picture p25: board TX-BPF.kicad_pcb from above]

Board: 11 copper layers, 62.0 x 28.6 mm, 21 parts (0 on the bottom side), 8 nets.

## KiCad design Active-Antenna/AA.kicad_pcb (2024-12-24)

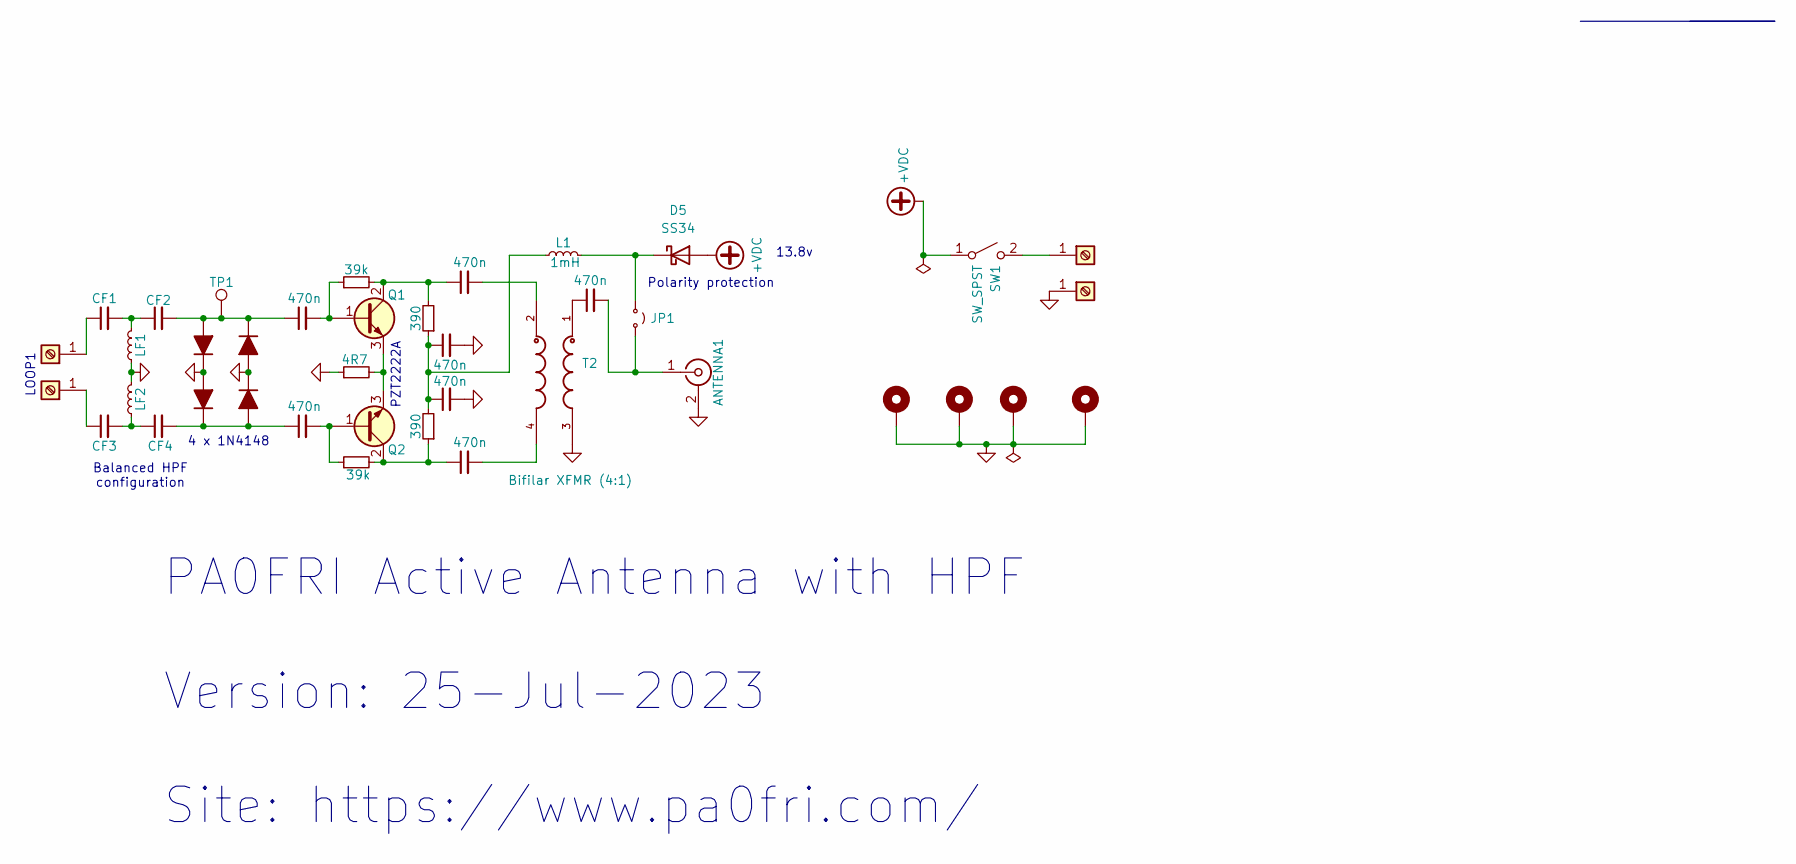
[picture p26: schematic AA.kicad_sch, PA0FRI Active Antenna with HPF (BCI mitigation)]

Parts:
ANTENNA1: SMA; SMA_Samtec_SMA-J-P-H-ST-EM1_EdgeMount
C1, C2, C3, C4, C5, C6, C7: 470n; C_1206_3216Metric_Pad1.33x1.80mm_HandSolder
CF1, CF2, CF3, CF4: 750p; C_0805_2012Metric_Pad1.18x1.45mm_HandSolder
D1, D2, D3, D4: 1N4148; D_DO-35_SOD27_P7.62mm_Horizontal
D5: SS34; D_SMA-SMB_Universal_Handsoldering
H1, H2, H3, H4: MountingHole_Pad; MountingHole_3.2mm_M3_Pad_Via
J1, J2, J3, J4: Screw_Terminal_01x01; TestPoint_THTPad_4.0x4.0mm_Drill2.0mm
JP1: Jumper_2_Small_Open; SolderJumper-2_P1.3mm_Open_RoundedPad1.0x1.5mm
L1: 1mH; L_Bourns-SRU8028_8.0x8.0mm
LF1, LF2: 1.8u; L_0805_2012Metric_Pad1.15x1.40mm_HandSolder
Q1, Q2: PZT2222A; SOT-223-3_TabPin2
R1: 4R7; R_1206_3216Metric_Pad1.30x1.75mm_HandSolder
R2, R3: 39k; R_2512_6332Metric
R4, R5: 390; R_2512_6332Metric
SW1: SW_SPST; PinSocket_1x02_P2.54mm_Vertical
T2: Bifilar XFMR (4:1); IND_SRF1260A-4R7Y-Longer-Pads
TP1: TestPoint; TestPoint_THTPad_4.0x4.0mm_Drill2.0mm

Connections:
+VDC: D5.2 (A), SW1.1 (A)
GND: ANTENNA1.2 (Ext), C3.2, C4.2, D1.1 (K), D2.2 (A), D3.1 (K), D4.2 (A), H1.1, H2.1, H3.1, H4.1, J3.1, LF1.1, LF2.2, R1.1, T2.3
unnamed: ANTENNA1.1 (In), C7.2, JP1.2 (B)
unnamed: C3.1, C4.1, L1.1, R4.1, R5.2
unnamed: C5.2, T2.2
unnamed: C6.2, T2.4
unnamed: C7.1, T2.1
unnamed: CF1.2, CF2.1, LF1.2
unnamed: CF3.2, CF4.1, LF2.1
unnamed: C1.1, CF2.2, D1.2 (A), D4.1 (K), TP1.1
unnamed: C2.1, CF4.2, D2.1 (K), D3.2 (A)
unnamed: D5.1 (K), JP1.1 (A), L1.2
unnamed: CF1.1, J1.1
unnamed: CF3.1, J2.1
unnamed: J4.1, SW1.2 (B)
unnamed: C1.2, Q1.1 (B), R2.1
unnamed: C5.1, Q1.2 (C), R2.2, R4.2
unnamed: Q1.3 (E), Q2.3 (E), R1.2
unnamed: C2.2, Q2.1 (B), R3.1
unnamed: C6.1, Q2.2 (C), R3.2, R5.1

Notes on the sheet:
PZT2222A
4 x 1N4148
Balanced HPF configuration
LOOP1
PA0FRI Active Antenna with HPF Version: 25-Jul-2023 Site: https://www.pa0fri.com/
13.8v
Polarity protection

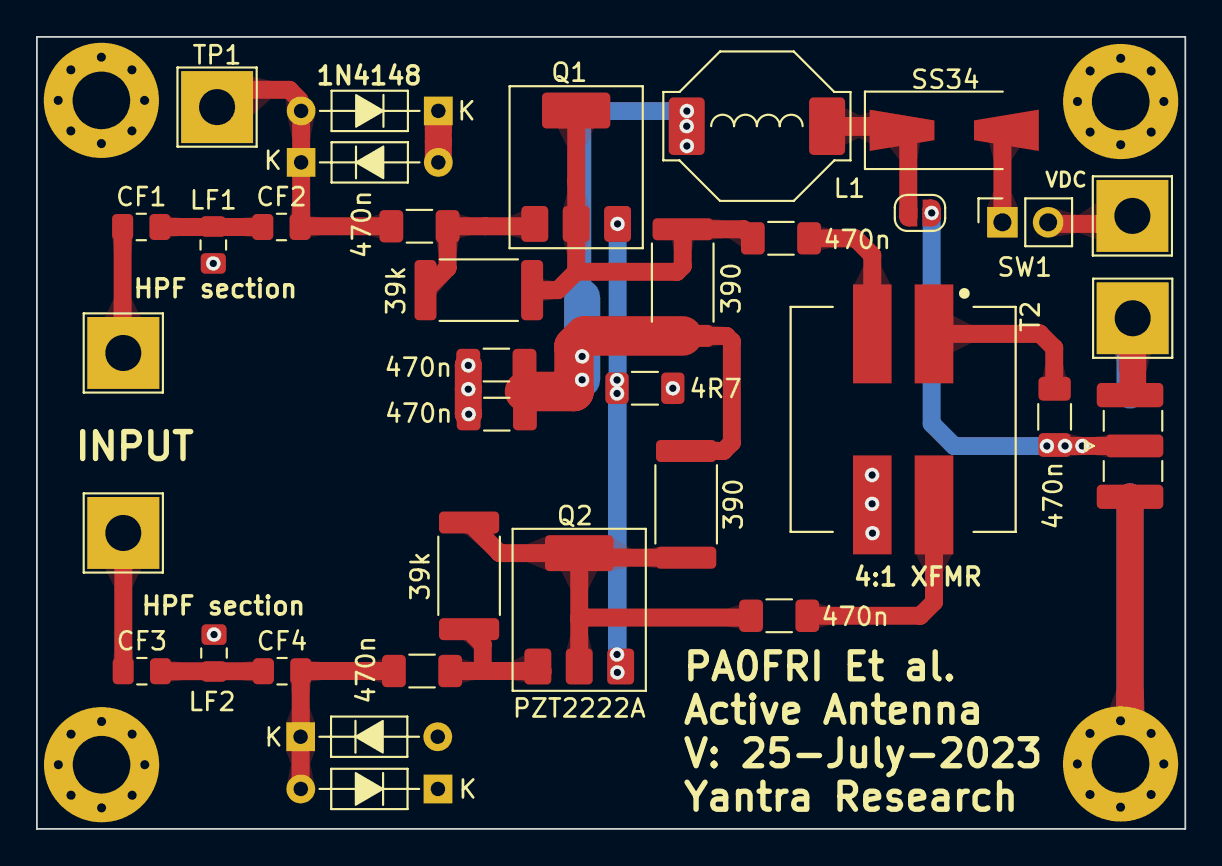
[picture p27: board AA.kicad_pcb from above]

Board: 2 copper layers, 63.8 x 44.0 mm, 39 parts (0 on the bottom side), 20 nets.

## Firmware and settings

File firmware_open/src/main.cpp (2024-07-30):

// DDX-v3 firmware

#include <string>
#include <ostream>

#include <stdio.h>
#include "pico/stdlib.h"
#include "pico/unique_id.h"
#include "analog_microphone.h"
#include "pico/multicore.h"

#include "usb_microphone.h"
#include "tusb.h"

#include "ddx_common.h"
#include "si5351.h"

#include <math.h>
#include <stdio.h>
#include <string.h>

#include "hash.h"

#include "hardware/i2c.h"
#include "hardware/timer.h"
#include "hardware/clocks.h"
#include "hardware/watchdog.h"

// ft8_lib stuff
#include "../ft8_lib/ft8/message.h"
#include "../ft8_lib/ft8/encode.h"
#include "../ft8_lib/ft8/constants.h"

#include "wspr_enc.h"

int symbolCount = 79;
int toneSpacing = 625;
#define FT8_TONE_SPACING 625  // ~6.25 Hz
#define FT8_DELAY 159  // Delay value for FT8
#define FT8_SYMBOL_COUNT 79
uint8_t tones[FT8_SYMBOL_COUNT];
int toneDelay = 159;

// #define DEBUG_ON 1

// CAT code
static uint8_t insideCat = 0;
unsigned char doingCAT = 0;
bool txCAT             = false;  // turned on if the transmitting due to a CAT command
bool message_available = false;
#define CAT_MAX 24
static char cat[CAT_MAX + 64];   // 64 avoids overflow
uint16_t offset = 1200;
static int sidx = 0;
char current_message[32];
char buffer[32];

#include "pico/stdio.h"
#include "pico/time.h"
#include "Adafruit_NeoPixel.hpp"

#define ONBOARD 16 // GP16 has 1 pixel NEOPIXEL strand connected to it

// Parameter 1 = number of pixels in strip
// Parameter 2 = Arduino pin number (most are valid)
// Parameter 3 = pixel type flags, add together as needed:
//   NEO_KHZ800  800 KHz bitstream (most NeoPixel products w/WS2812 LEDs)
//   NEO_KHZ400  400 KHz (classic 'v1' (not v2) FLORA pixels, WS2811 drivers)
//   NEO_GRB     Pixels are wired for GRB bitstream (most NeoPixel products)
//   NEO_RGB     Pixels are wired for RGB bitstream (v1 FLORA pixels, not v2)
//   NEO_RGBW    Pixels are wired for RGBW bitstream (NeoPixel RGBW products)
Adafruit_NeoPixel onboard = Adafruit_NeoPixel(1, ONBOARD, NEO_RGB + NEO_KHZ800);

// IMPORTANT: To reduce NeoPixel burnout risk, add 1000 uF capacitor across
// pixel power leads, add 300 - 500 Ohm resistor on first pixel's data input
// and minimize distance between Arduino and first pixel.  Avoid connecting
// on a live circuit...if you must, connect GND first.
// additional functions
void colorWipe(uint32_t c, uint8_t wait);

// configuration
const struct analog_microphone_config config = {
  // GPIO to use for input, must be ADC compatible (GPIO 26 - 28)
  .gpio = 26,
  // bias voltage of microphone in volts
  .bias_voltage = 1.65, // 3.3v / 2
  // sample rate in Hz
  .sample_rate = 16000,
  // number of samples to buffer
  .sample_buffer_size = SAMPLE_BUFFER_SIZE,
};

// variables
int16_t sample_buffer[SAMPLE_BUFFER_SIZE];
volatile int samples_read = 0;

void on_analog_samples_ready()
{
  samples_read = analog_microphone_read(sample_buffer, SAMPLE_BUFFER_SIZE);
}

void on_usb_microphone_tx_ready()
{
  usb_microphone_write(sample_buffer, sizeof(sample_buffer));
}

void cdc_task(void);

// Automatic calibration stuff
uint32_t f_hi_;
void pwm_int_() {
  pwm_clear_irq(7);
  f_hi_++;
}

void band_change(int idx)
{
  si5351_set_freq((freq) * 100ULL, SI5351_CLK1); // CLK1 is RX clock
}

/* Button handling code */
int btnDown(int btn) {
  if (gpio_get(btn) == 1)
    return 0;
  else
    return 1;

  return 0;
}

static void str_to_upper(char *dist, const char *str)
{
  while (*str) *dist++ = toupper(*str++);
  *dist = 0;
}

int wspr_encode(char *call, char *grid, char *dBm, uint8_t *symbols)
{
  char call_u[11], grid_u[7];

  // Call
  if ((strlen(call) < 2) || (strlen(call) > 10)) {
    printf("The length of callsign %s is invalid.\n", call);
    return -1;
  }
  str_to_upper(call_u, call);
  // for Swaziland 3DA0YZ, 3D0YZ will be used for proper decoding
  if (strncmp(call_u, "3DA0", 4) == 0) {
    size_t i;
    for (i = 3; i < strlen(call); i++) {
      call[i - 1] = call[i];
    }
    call[i - 1] = 0;
  }
  str_to_upper(call_u, call);

  // Grid
  if ((strlen(grid) != 4) && (strlen(grid) != 6)) {
    printf("The length of grid locator %s is invalid.\n", grid);
    return -1;
  }
  str_to_upper(grid_u, grid);

  printf("WSPR Message: %s %s %s\n", call, grid, dBm);

  // invoke encoder function to generate symbols
  uint8_t msgtype = wspr_enc(call, grid, dBm, symbols);

  /* printf("Channel symbols: (message type %d)", msgtype);
    int i;
    for (i = 0; i < 162; i++) {
      if (i%30 == 0) {
          printf("\n      %d", symbols[i]);
      } else {
          printf(" %d", symbols[i]);
      }
    }
    printf("\n"); */

  return 0;
}

void active_sleep_ms(unsigned int delay_by) {
  sleep_ms(delay_by);

  /* unsigned long timeStart = millis();
    while (millis() - timeStart <= delay_by) {
    // Background Work
    } */
}

int checkButton(int btn) {
  int ret = 0;

  // only if the button is pressed
  if (!btnDown(btn))
    return ret;
  active_sleep_ms(50);
  if (!btnDown(btn)) // debounce
    return ret;

  ret = 1;
  if (btn == ABORT_BTN) {
    gpio_put(PTT, 0);
    si5351_set_clock_pwr(SI5351_CLK0, 0);
    si5351_output_enable(SI5351_CLK0, 0);
  } else if (btn == TUNE_BTN) {
    gpio_put(ATU_PIN, 1);
    // Turn on the output
    gpio_put(PTT, 1);
    sleep_ms(12); // Important delay for relay switching (for OEN 46 Series)
    si5351_set_freq(((freq + offset) * 100ULL), SI5351_CLK0);
    si5351_set_clock_pwr(SI5351_CLK0, 1);
    si5351_output_enable(SI5351_CLK0, 1);
    colorWipe(onboard.Color(255, 0, 0), 0); // R
    sleep_ms(3500); // Full tune cycle (LDG Z-100 Plus Automatic Tuner)
    // Turn off the output
    si5351_set_clock_pwr(SI5351_CLK0, 0);
    si5351_output_enable(SI5351_CLK0, 0);
    gpio_put(PTT, 0);
    // colorWipe(onboard.Color(0, 255, 0), 0); // G
    colorWipe(onboard.Color(0, 0, 0), 0); // Off

    gpio_put(ATU_PIN, 0);
  }

  // wait for the button to go up again
  while (btnDown(btn))
    active_sleep_ms(10);
  active_sleep_ms(50);

  return ret;
}

bool start_tx = false;

void tx()
{
  uint8_t i;

  gpio_put(PTT, 1);
  sleep_ms(12); // Important delay for relay switching (for OEN 46 Series)
#ifndef DEBUG_ON
  si5351_set_clock_pwr(SI5351_CLK0, 1);
  si5351_output_enable(SI5351_CLK0, 1);
  si5351_drive_strength(SI5351_CLK0, SI5351_DRIVE_8MA); // Set max. power for TX (UCC driver)
  colorWipe(onboard.Color(255, 0, 0), 0); // R
#endif
  for (i = 0; i < symbolCount; i++) {
#ifndef DEBUG_ON
    si5351_set_freq(((freq + offset) * 100ULL) + (tones[i] * toneSpacing), SI5351_CLK0);
#endif
    sleep_ms(toneDelay);
  }

  // Turn off the output
#ifndef DEBUG_ON
  si5351_set_clock_pwr(SI5351_CLK0, 0);
  si5351_output_enable(SI5351_CLK0, 0);
#endif
  gpio_put(PTT, 0);
#ifndef DEBUG_ON
  si5351_set_freq((freq) * 100ULL, SI5351_CLK1); // CLK1 is RX clock, reinit rx_clock_line?
  colorWipe(onboard.Color(0, 0, 0), 0); // Off
#endif
}

void core1_entry() {
  int ret;
  while (1) {
    // checkButton(ABORT_BTN);
    // checkButton(TUNE_BTN);
    if (start_tx) {
      tx();
      start_tx = false;
    }
    sleep_ms(10);
  }
}

void colorWipe(uint32_t c, uint8_t wait) {
  for (uint16_t i = 0; i < onboard.numPixels(); i++) {
    onboard.setPixelColor(i, c);
    onboard.show();
    sleep_ms(wait);
  }
}

void crash_with_led()
{
  while (1) {
    colorWipe(onboard.Color(255, 0, 0), 100); // Red
    colorWipe(onboard.Color(0, 255, 0), 100); // Green
    colorWipe(onboard.Color(0, 0, 255), 100); // Blue
  }
}

void finite_crash_with_led()
{
  int i = 7;

  while (i >= 0) {
    colorWipe(onboard.Color(255, 0, 0), 100); // Red
    colorWipe(onboard.Color(0, 255, 0), 100); // Green
    colorWipe(onboard.Color(0, 0, 255), 100); // Blue
    i = i - 1;
  }
}

static void hash_to_string(char string[65], const uint8_t hash[32])
{
  size_t i;
  for (i = 0; i < 32; i++) {
    string += sprintf(string, "%02x", hash[i]);
  }
}

void watchdog_task();

int main(void)
{
  int ret;

  stdio_init_all();

  // Safety first
  gpio_init(PTT);
  gpio_set_dir(PTT, GPIO_OUT);
  gpio_put(PTT, 0);

  // NeoPixel stuff
  onboard.begin();
  onboard.setBrightness(25);
  onboard.show(); // Initialize all pixels to 'off'

  // sleep_ms(5000);

#ifndef DEBUG_ON
  // Initialize the Si5351 --- this will go into an infinte loop in case of problems!
  while (1) {
    ret = si5351_init(0x60, SI5351_CRYSTAL_LOAD_8PF, 26000000, 0); // I am using a 26 MHz TCXO
    if (!ret) {
      // crash_with_led(); // Dhiru's hack
      // watchdog_reboot(0, 0, 1000);
      colorWipe(onboard.Color(255, 0, 0), 100); // Red
      sleep_ms(500);
      colorWipe(onboard.Color(255, 255, 0), 100);
      sleep_ms(500);
    }
    else {
      break;
    }
  }

  colorWipe(onboard.Color(0, 0, 0), 0); // Off
  // si5351_init(0x60, SI5351_CRYSTAL_LOAD_8PF, 0, 0);
  si5351_output_enable(SI5351_CLK0, 0); // Turn of TX first - safety!
  // CLK1 is RX clock
  si5351_set_freq(freq * 100ULL, SI5351_CLK1);
  si5351_drive_strength(SI5351_CLK1, SI5351_DRIVE_4MA); // Set a bit reduced power for RX
  si5351_drive_strength(SI5351_CLK0, SI5351_DRIVE_8MA); // Set max. power for TX (UCC driver)
#endif

  // Initialize GPIOs
  gpio_init(TUNE_BTN);
  gpio_init(ABORT_BTN);
  gpio_set_dir(TUNE_BTN, GPIO_OUT);
  gpio_set_dir(ABORT_BTN, GPIO_OUT);
  gpio_pull_up(TUNE_BTN);
  gpio_pull_up(ABORT_BTN);
  gpio_set_dir(CAL, GPIO_IN);
  gpio_put(ATU_PIN, 0);

  // "Pico's" serial number
  int len = 16;
  char buff[len + 1] = "";
  pico_get_unique_board_id_string((char *)buff, len + 1);
#ifdef DEBUG_ON_VERBOSE
  printf(buff);
#endif

  uint8_t hash[32];
  char hash_string[65];
  calc_sha_256(hash, buff, len);
  hash_to_string(hash_string, hash);

  // Turn on RX
  gpio_put(PTT, 0);

  // EEPROM.get(4, cal_factor);
  // si5351_set_correction(cal_factor, SI5351_PLL_INPUT_XO);

  // Pico soundcard stuff
  if (analog_microphone_init(&config) < 0) {
    while (1) {
      tight_loop_contents();
    }
  }
  analog_microphone_set_samples_ready_handler(on_analog_samples_ready);
  if (analog_microphone_start() < 0) { // start capturing data from the analog microphone
    while (1) {
      tight_loop_contents();
    }
  }
  usb_microphone_init();
  usb_microphone_set_tx_ready_handler(on_usb_microphone_tx_ready);

  // note!
  multicore_launch_core1(core1_entry);

  while (1) {
    // run the USB microphone task continuously
    usb_microphone_task(); // calls tud_task() -> TinyUSB device task

    cdc_task(); // CAT handler -> should return fast!

    watchdog_task();
  }
  return 0;
}

// Variables
uint64_t freq = 28074000ULL; // Start on the 10m by default
uint64_t new_freq;
int32_t cal_factor = 0; // Sorted out by auto-calibration algorithm, now not required by tcxo ;)

absolute_time_t tx_timestamp;

void watchdog_task() {
  watchdog_update();

  if (start_tx == true) {
    // Another safeguard for FT8
    absolute_time_t current_timestamp = get_absolute_time();
    if (absolute_time_diff_us(tx_timestamp, current_timestamp) > 15000000ULL) {
      si5351_set_clock_pwr(SI5351_CLK0, 0);
      si5351_output_enable(SI5351_CLK0, 0);
      gpio_put(PTT, 0);
      finite_crash_with_led();
      watchdog_reboot(0, 0, 1000);
    }
  }
}

char buf[64];

extern "C" {
	void packtext77(const char* text, uint8_t* b77);
}

//--------------------------------------------------------------------+
// USB CDC
//--------------------------------------------------------------------+
// Dhiru -> Don't block in this task at all - it impacts the audio quality!
void cdc_task(void)
{
  if (tud_cdc_available())
  {
    memset(buf, 0, sizeof(buf));
    uint32_t count = tud_cdc_read(buf, sizeof(buf)); // count can be 1 here - so we have to piece 'strings' together ourselves
    // printf(count);
    // printf(sidx);

    memcpy(cat + sidx, buf, count);
    // printf(cat);
    cat[CAT_MAX - 1] = 0;
    sidx = (sidx + count) % CAT_MAX; // not perfect

    // Protocol -> a valid message starts with '*' and also ends with '*'
    char *s = strchr(cat, '*');
    char *e = strrchr(cat, '*');
    if (s != e && s != NULL && e != NULL ) { /* We may have a valid message */
      if (*(s + 1) == 'v') { // 'ready' debug
        char *response = (char *)"r";
        // Send indication for ready!
        tud_cdc_write(response, 1);
        tud_cdc_write_flush();
      } else if (*(s + 1) == 'o') {
        char *response = (char *)"o";
        offset = atoi(strtok(s + 2, "*"));
      } else if (*(s + 1) == 'm') { // message load
        char *response = (char *)"m";
        message_available = true;
        strncpy(current_message, strtok(s + 2, "*"), 32 - 1);
#ifdef DEBUG_ON_VERBOSE
        printf(current_message);
#endif
        ftx_message_t msg;
        ftx_message_rc_t rc = ftx_message_encode(&msg, NULL, current_message);
        bool is_ft4 = false;
        if (rc != FTX_MESSAGE_RC_OK) {
#ifdef DEBUG_ON_VERBOSE
          printf("Cannot parse message!\n");
          printf("RC = %d\n", (int)rc);
#endif
          // sleep_ms(1000);
          if (strlen(current_message) <= 13) {
            packtext77(current_message, (uint8_t *)&msg.payload);
            colorWipe(onboard.Color(0, 255, 255), 0); // Blue-green (cyan)
          }
	}
        int num_tones = (is_ft4) ? FT4_NN : FT8_NN;
        // Second, encode the binary message as a sequence of FSK tones
        if (is_ft4) {
          ft4_encode(msg.payload, tones);
        } else {
          ft8_encode(msg.payload, tones);
        }
      } else if (*(s + 1) == 't') { // tx on
        if (message_available) {
          char *response = (char *)"t";
          start_tx = true;
          watchdog_enable(7000, 1);
          tx_timestamp = get_absolute_time();
        }
      } else if (*(s + 1) == 'z') { // ptt off
        if (message_available) {
          char *response = (char *)"z";
#ifdef DEBUG_ON_VERBOSE
          printf("PTT OFF");
#endif
          gpio_put(PTT, 0);
        }
      } else if (*(s + 1) == 'p') { // ptt on
        if (message_available) {
          char *response = (char *)"p";
#ifdef DEBUG_ON_VERBOSE
          printf("PTT ON");
#endif
          // gpio_put(PTT, 1); // Disabled for safety
        }
      } else if (*(s + 1) == 'y') { // debug
        if (message_available) {
          char *response = (char *)"y";
        }
      } else if (*(s + 1) == 's') { // 'style' (digital mode)
        strncpy(buffer, strtok(s + 2, "*"), 32 - 1);
	puts(buffer);
      } else if (*(s + 1) == 'f') { // frequency
        char *response = (char *)"f";
        char *f = strtok(s + 2, "*");
        char *ptr;
        new_freq = strtoul(f, &ptr, 10);
        freq = new_freq;
        uint8_t band_idx;
        /* switch (new_freq) {
          case 7074000:
            band_idx = 0;
            break;
          case 14074000:
            band_idx = 1;
            break;
          case 21074000:
            band_idx = 2;
            break;
          case 28074000:
            band_idx = 3;
            break;
          } */
        // band_change(band_idx);
#ifndef DEBUG_ON
        si5351_set_freq((freq) * 100ULL, SI5351_CLK1); // CLK1 is RX clock
#endif
#ifdef DEBUG_ON_VERBOSE
        printf("Frequency switch - CAREFUL!");
#endif
      }
      // Clear stuff
      sidx = 0;
      memset(cat, 0, CAT_MAX * 2);
      // colorWipe(onboard.Color(0, 255, 0), 100); // Green
    }
  }
}

// Invoked when cdc when line state changed e.g connected/disconnected
void tud_cdc_line_state_cb(uint8_t itf, bool dtr, bool rts)
{
  (void) itf;
  (void) rts;

  if (dtr)
  {
    // Terminal connected
  } else
  {
    // Terminal disconnected
  }
}

// Invoked when CDC interface received data from host
void tud_cdc_rx_cb(uint8_t itf)
{
  (void) itf;
}

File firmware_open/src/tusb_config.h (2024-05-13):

/*
 * The MIT License (MIT)
 *
 * Copyright (c) 2019 Ha Thach (tinyusb.org)
 *
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
 */

#ifndef _TUSB_CONFIG_H_
#define _TUSB_CONFIG_H_

#ifdef __cplusplus
extern "C" {
#endif

//--------------------------------------------------------------------
// COMMON CONFIGURATION
//--------------------------------------------------------------------

// defined by compiler flags for flexibility
#ifndef CFG_TUSB_MCU
#error CFG_TUSB_MCU must be defined
#endif

#if CFG_TUSB_MCU == OPT_MCU_LPC43XX || CFG_TUSB_MCU == OPT_MCU_LPC18XX || CFG_TUSB_MCU == OPT_MCU_MIMXRT10XX
#define CFG_TUSB_RHPORT0_MODE       (OPT_MODE_DEVICE | OPT_MODE_HIGH_SPEED)
#else
#define CFG_TUSB_RHPORT0_MODE       OPT_MODE_DEVICE
#endif

#ifndef CFG_TUSB_OS
#define CFG_TUSB_OS                 OPT_OS_NONE
#endif

#ifndef CFG_TUSB_DEBUG
#define CFG_TUSB_DEBUG              0
#endif

// CFG_TUSB_DEBUG is defined by compiler in DEBUG build
// #define CFG_TUSB_DEBUG           0

/* USB DMA on some MCUs can only access a specific SRAM region with restriction on alignment.
 * Tinyusb use follows macros to declare transferring memory so that they can be put
 * into those specific section.
 * e.g
 * - CFG_TUSB_MEM SECTION : __attribute__ (( section(".usb_ram") ))
 * - CFG_TUSB_MEM_ALIGN   : __attribute__ ((aligned(4)))
 */
#ifndef CFG_TUSB_MEM_SECTION
#define CFG_TUSB_MEM_SECTION
#endif

#ifndef CFG_TUSB_MEM_ALIGN
#define CFG_TUSB_MEM_ALIGN          __attribute__ ((aligned(4)))
#endif

//--------------------------------------------------------------------
// DEVICE CONFIGURATION
//--------------------------------------------------------------------

#ifndef CFG_TUD_ENDPOINT0_SIZE
#define CFG_TUD_ENDPOINT0_SIZE    64
#endif

//------------- CLASS -------------//
#define CFG_TUD_CDC               1
#define CFG_TUD_MSC               0
#define CFG_TUD_HID               0
#define CFG_TUD_MIDI              0
#define CFG_TUD_AUDIO             1
#define CFG_TUD_VENDOR            0

//--------------------------------------------------------------------
// AUDIO CLASS DRIVER CONFIGURATION
//--------------------------------------------------------------------

// Have a look into audio_device.h for all configurations

#define CFG_TUD_AUDIO_FUNC_1_DESC_LEN                                 TUD_AUDIO_MIC_ONE_CH_DESC_LEN
#define CFG_TUD_AUDIO_FUNC_1_N_AS_INT                                 1                                       // Number of Standard AS Interface Descriptors (4.9.1) defined per audio function - this is required to be able to remember the current alternate settings of these interfaces - We restrict us here to have a constant number for all audio functions (which means this has to be the maximum number of AS interfaces an audio function has and a second audio function with less AS interfaces just wastes a few bytes)
#define CFG_TUD_AUDIO_FUNC_1_CTRL_BUF_SZ                              64                                      // Size of control request buffer

#define CFG_TUD_AUDIO_ENABLE_EP_IN                                    1
#define CFG_TUD_AUDIO_FUNC_1_N_BYTES_PER_SAMPLE_TX                    2                                       // Driver gets this info from the descriptors - we define it here to use it to setup the descriptors and to do calculations with it below
#define CFG_TUD_AUDIO_FUNC_1_N_CHANNELS_TX                            1                                       // Driver gets this info from the descriptors - we define it here to use it to setup the descriptors and to do calculations with it below - be aware: for different number of channels you need another descriptor!
#define CFG_TUD_AUDIO_EP_SZ_IN                                        (16 + 1) * CFG_TUD_AUDIO_FUNC_1_N_BYTES_PER_SAMPLE_TX * CFG_TUD_AUDIO_FUNC_1_N_CHANNELS_TX      // 16 Samples (16 kHz) x 2 Bytes/Sample x 1 Channel
#define CFG_TUD_AUDIO_FUNC_1_EP_IN_SZ_MAX                             CFG_TUD_AUDIO_EP_SZ_IN                  // Maximum EP IN size for all AS alternate settings used
#define CFG_TUD_AUDIO_FUNC_1_EP_IN_SW_BUF_SZ                          CFG_TUD_AUDIO_EP_SZ_IN

// CDC FIFO size of TX and RX (CDC stuff)
#define CFG_TUD_CDC_RX_BUFSIZE                    64
#define CFG_TUD_CDC_TX_BUFSIZE                    64

#ifdef __cplusplus
}
#endif

#endif /* _TUSB_CONFIG_H_ */

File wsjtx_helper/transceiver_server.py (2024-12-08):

#!/usr/bin/env python3
#pylint: disable-msg=missing-function-docstring,line-too-long,invalid-name,too-many-instance-attributes,consider-using-f-string

"""
WSJT-X plugin (helper script) for radios using the Direct-RF-Synthesis technique.

Sources:

- https://github.com/rstagers/WSJT-X/blob/master/WSJTXClass.py
- https://github.com/agustinmartino/wsjtx_transceiver_interface
"""

import sys
import time
import socket
import struct
import datetime

try:
    import serial
    import serial.tools.list_ports
except ImportError:
    print("The 'pyserial' library is missing. Please install it with 'python3 -m pip install pyserial' command.")
    sys.exit(1)

a = serial.tools.list_ports.comports()
serial_port = ""
for w in a:
    if "cafe" in w.hwid.lower() or "4011" in w.hwid.lower():
        serial_port = w.device

if not serial_port:
    print("We could NOT find the 'DDX' radio. Please re-connect the radio and try again.")
    sys.exit(1)

BAUD_RATE = 115200

import serial
import serial.tools.list_ports


class WSJTX_Packet():
    """
    Header class for all WSJT received packets. This class handles the header
    and will create class for handling the packet depending on the packet type
    in the header.
    """
    def __init__(self, pkt, idx):
        self.index = idx  # Keeps track of where we are in the packet parsing
        self.packet = pkt
        self.MagicNumber = 0
        self.SchemaVersion = 0
        self.PacketType = 0
        self.ClientID = ""

    # Methods to extract the different types of data in the packet.  These are shared with all
    # the other packet classes.
    def readutf8(self):
        strLength = self.getInt32()
        # BUG what happens if string length is zero?
        if strLength > 0:
            stringRead = struct.unpack(">"+str(strLength)+"s",
                    self.packet[self.index:strLength+self.index])
            self.index += strLength
            return stringRead[0].decode('utf-8')
        return ""

    def getDateTime(self):
        TimeOffset = 0
        DateOff = self.getLongLong()
        TimeOff = self.getuInt32()
        TimeSpec = self.getByte()
        if TimeSpec == 2:
            TimeOffset = self.getInt32()
        return (DateOff, TimeOff, TimeSpec, TimeOffset)

    def getByte(self):
        data = struct.unpack(">B", self.packet[self.index:self.index+1])
        self.index += 1
        return data[0]

    def getBool(self):
        data = struct.unpack(">?", self.packet[self.index:self.index+1])
        self.index += 1
        return data[0]

    def getInt32(self):
        data = struct.unpack(">i", self.packet[self.index:self.index+4])
        self.index += 4
        return data[0]

    def getuInt32(self):
        data = struct.unpack(">I", self.packet[self.index:self.index+4])
        self.index += 4
        return data[0]

    def getLongLong(self):
        data = struct.unpack(">Q", self.packet[self.index:self.index+8])
        self.index += 8
        return data[0]

    def getDouble(self):
        data = struct.unpack(">d", self.packet[self.index:self.index+8])
        self.index += 8
        return data[0]

    def Decode(self):
        # print(self.packet, len(self.packet))
        self.MagicNumber = self.getuInt32()
        self.SchemaVersion = self.getuInt32()
        self.PacketType = self.getuInt32()
        self.ClientID = self.readutf8()

class WSJTX_Status(WSJTX_Packet):
    """
    Packet Type 1 Status:
    WSJT-X  sends this  status message  when various  internal state changes to
    allow the server to  track the relevant state of each client without the
    need for  polling commands. The current state changes that generate status
    messages are:

    - Application start up,
    - "Enable Tx" button status changes,
    - Dial frequency changes,
    - Changes to the "DX Call" field,
    - Operating mode, sub-mode or fast mode changes,
    - Transmit mode changed (in dual JT9+JT65 mode),
    - Changes to the "Rpt" spinner,
    - After an old decodes replay sequence (see Replay below),
    - When switching between Tx and Rx mode,
    - At the start and end of decoding,
    - When the Rx DF changes,
    - When the Tx DF changes,
    - When the DE call or grid changes (currently when settings are exited),
    - When the DX call or grid changes,
    - When the Tx watchdog is set or reset.
    """
    def __init__(self, pkt, idx):
        WSJTX_Packet.__init__(self, pkt, idx)
        self.Frequency = 0
        self.Mode = ""
        self.DXCall = ""
        self.Report = ""
        self.TxMode = ""
        self.TxEnabled = False
        self.Transmitting = False
        self.Decoding = False
        self.RxDF = 0
        self.TxDF = 0
        self.DECall = ""
        self.DEgrid = ""
        self.DXgrid = ""
        self.TxWatchdog = False
        self.Submode = ""
        self.Fastmode = False
        self.SpecialOpMode = False
        self.FrequencyTolerance = 0
        self.TrPeriod = 0
        self.ConfigurationName = ""
        self.TxMessage = ""

    def Decode(self):
        """
        https://github.com/jtdx-project/jtdx/blob/master/MessageServer.cpp#L221

        Note: JTDX and jtdx_improved do NOT send 'TxMessage', hence they are NOT compatible!

        https://sourceforge.net/p/wsjt/wsjtx/ci/master/tree/UDPExamples/MessageServer.cpp#l253
        """
        self.Frequency = self.getLongLong()
        self.Mode = self.readutf8()
        self.DXCall = self.readutf8()
        self.Report = self.readutf8()
        self.TxMode = self.readutf8()
        self.TxEnabled = self.getBool()
        self.Transmitting = self.getBool()
        self.Decoding = self.getBool()
        self.RxDF = self.getuInt32()
        self.TxDF = self.getuInt32()
        self.DECall = self.readutf8()
        self.DEgrid = self.readutf8()
        self.DXgrid = self.readutf8()
        self.TxWatchdog = self.getBool()
        self.Submode = self.readutf8()
        self.Fastmode = self.getBool()
        self.SpecialOpMode = self.getBool()
        self.FrequencyTolerance = self.getuInt32()
        self.TrPeriod = self.getuInt32()
        self.ConfigurationName = self.readutf8()
        self.TxMessage = self.readutf8()

sport = None
while not sport:
    try:
        sport = serial.Serial(serial_port, BAUD_RATE, timeout=0.5)
    except serial.serialutil.SerialException:
        print("> Unable to open serial port (%s)..." % serial_port)
    time.sleep(1)

# Global variables
freq_offset = 1200
frequency = 28074000
mode = "FT8"
current_msg = ""

# Connection for WSJT-X
UDP_IP = "127.0.0.1"
UDP_PORT = 2237
sock = socket.socket(socket.AF_INET, socket.SOCK_DGRAM)
sock.bind((UDP_IP, UDP_PORT))

def load_msg(msg):
    print("> Load message into transmitter...")
    sport.write(b'*m')
    sport.write(msg.encode("ascii"))
    sport.write(b'*')
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

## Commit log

2024-05-13 Public production release
    [14-MHz-BPF-Qucs-Studio.sch, 1564889-62.stp, 1566143-62.stp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]
2024-07-30 A new beginning...
    [1564889-62.stp, 1566143-62.stp, 22-23-2021.stp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]
2024-08-09 Files for JLCPCBA process
    [1564889-62.stp, 1566143-62.stp, 22-23-2021.stp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]
2024-09-23 Changes from Windows PC
    [1564889-62.stp, 1566143-62.stp, 22-23-2021.stp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]
2024-10-03 Pico 2 compatibility
    [1564889-62.stp, 1566143-62.stp, 22-23-2021.stp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]
2024-10-04 Final touches...
    [BOM-DDX-Commercial-3.csv, DDX-Commercial-3.kicad_pcb, DDX-Commercial-3.kicad_sch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]
2024-10-04 Manual for DDX
    [14-MHz-BPF-Qucs-Studio.sch, 1564889-62.stp, 1566143-62.stp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]
2024-11-01 Progress on DDX manual
    [1564889-62.stp, 1566143-62.stp, 22-23-2021.stp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]
2024-11-02 Minor tweaks for production
    [DDX-Commercial-3.kicad_pcb, DDX-Commercial-3.kicad_sch, DDX-Commercial-7.kicad_pcb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]
2024-11-26 Work on DDX-EVO-7 and Pico-WSPR-TX-board
    [1564889-62.stp, 1566143-62.stp, 22-23-2021.stp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]
2024-12-01 JLCPCBA files
    [1564889-62.stp, 1566143-62.stp, 22-23-2021.stp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]
2024-12-08 More files
    [1564889-62.stp, 1566143-62.stp, 22-23-2021.stp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]
2024-12-21 Work on CWX
    [CON-SMA-EDGE-S--3DModel-STEP-56544.STEP, CWX-Commercial-1.kicad_pcb, CWX-Commercial-1.kicad_sch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]
2024-12-23 A new start...
    [1564889-62.stp, 1566143-62.stp, 22-23-2021.stp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]
2024-12-24 New projects...
    [1564889-62.stp, 1566143-62.stp, 22-23-2021.stp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]
